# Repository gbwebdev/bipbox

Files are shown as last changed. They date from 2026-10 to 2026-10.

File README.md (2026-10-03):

# Bipbox

A self-hosted communication device for children — a wooden box with a thermal
printer, a telegraph key and a walkie-talkie, so that two kids in two different
homes can write, beep and talk to each other.

> **Status: in development.** The hardware exists (two boxes built); the
> software is being written. See [`docs/architecture.md`](docs/architecture.md).

## What it does

| Feature | |
|---|---|
| **Telex** | Family members log into a web page and send a text, a drawing or a photo. It prints on the box's thermal printer within seconds. |
| **Telegraphy** | Press the button on your box and the orange lamp lights up on the other one, with an optional beep. Nothing more — that is the charm. |
| **VoIP** | Squeeze the PTT on the shoulder speakermic and talk; your voice comes out of the other box's speaker. |

Boxes are grouped into **channels**. Everyone in a channel can beep and talk to
each other. People without a box can join from a browser.

## Hardware

Each box contains a Raspberry Pi Zero W, a MeanWell RS15-5 supply, a 4-port USB
hub, a USB sound card, an ESC/POS thermal printer and a homemade HAT that drives
four status lamps through a 74HCT595 and reads the buttons.

KiCad and FreeCAD sources are in [`CAD/`](CAD/) so you can build your own.

## Repository layout

```
server/   FastAPI server + Janus, deployed with docker-compose
device/   bipboxd daemon and the Pi's local management console
image/    pi-gen configuration producing a ready-to-flash SD image
docs/     architecture, specifications, hardware notes
CAD/      KiCad (HAT) and FreeCAD (enclosure)
```

## Documentation

| | |
|---|---|
| [`docs/architecture.md`](docs/architecture.md) | the design: topology, pin map, data model, protocol, security |
| [`docs/voip-options.md`](docs/voip-options.md) | why the voice path is Janus AudioBridge and not Mumble or WebRTC |
| [`docs/open-questions.md`](docs/open-questions.md) | the decisions behind the design, and why |
| [`docs/workflow.md`](docs/workflow.md) | branches, commits, releases |
| [`context.md`](context.md) | the original description of the project |

## Hardware bring-up

Before any of the software exists, the HAT can be tested on its own:

```bash
sudo apt install python3-spidev python3-gpiozero
sudo python3 device/tools/wiring_test.py
```

It discovers the shift-register bit order, measures button bounce, finds a
speaker-safe volume ceiling and prints a test ticket. See
[architecture.md §3.5](docs/architecture.md).

## Licensing

Two licences, scoped by what they cover:

| | |
|---|---|
| **Software** — everything outside `CAD/` | [MIT](LICENSE) |
| **Hardware** — the KiCad and FreeCAD sources in `CAD/` | [CERN-OHL-S v2](CAD/LICENSE) (strongly reciprocal) |

So you may do as you like with the code, and if you build on the board or the
enclosure and distribute the result, those improvements stay open.

## Acknowledgements

Bipbox grows out of [telex](https://github.com/gbwebdev/telex), an earlier
message-to-thermal-printer project; its printer handling, ESC/POS layout and
drawing tool are carried over here.

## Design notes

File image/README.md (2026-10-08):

# Golden image workflow

Capturing a prepared card and re-flashing it, so setting up a box is minutes
rather than an evening. This is the interim approach; `pi-gen` (phase 6) will
eventually build the image from source instead, which is reproducible and
diffable where a cloned card is neither.

## What belongs in the image, and what does not

| In the image | Per box, applied after flashing |
|---|---|
| Raspberry Pi OS Lite (Bookworm, **armhf** — the Pi Zero W is ARMv6) | hostname |
| `config.txt` | device UUID and server credentials |
| apt packages | **calibration** — the LED bit order is a property of each harness (§3.2) |
| WiFi credentials *(by default — see below)* | SSH host keys and `machine-id` (regenerated on first boot) |

Getting that split wrong is not a tidiness issue. Two boxes sharing a
`machine-id` derive the same DHCP client identifier and fight over a lease,
which presents as "the second box never appears on the network" — a long way
from its cause. And box A's calibration on box B lights the wrong lamps.

## 1. Prepare the card you want to clone

Install everything slow, so you never wait for it again. On a Pi Zero these
take a while:

```bash
sudo apt update && sudo apt full-upgrade -y
sudo apt install -y \
    python3-spidev python3-gpiozero python3-lgpio \
    python3-venv libusb-1.0-0 \
    gstreamer1.0-tools gstreamer1.0-plugins-base \
    gstreamer1.0-plugins-good gstreamer1.0-alsa alsa-utils \
    avahi-daemon git
```

Settle `config.txt` (§3.1) and confirm the box boots and joins WiFi **before**
capturing. An image made from a card you have not booted is a guess.

## 2. Strip box-specific identity

On the Pi, as root, immediately before shutting down:

```bash
sudo bash image/prepare-for-capture.sh              # keeps WiFi
sudo bash image/prepare-for-capture.sh --wipe-wifi  # for a shareable image
sudo shutdown -h now
```

### WiFi: kept by default, and why

Keeping the credentials is what makes a flashed card useful immediately — it
joins the bench network on its own and you can SSH straight in. **Never share
such an image**: NetworkManager stores the PSK in plain text.

Use `--wipe-wifi` for an image you intend to publish, or for a box destined
for another house, where your credentials would be wrong anyway. A card with
no known network falls back to AP mode and is configured from the local
console (§9.3) — which is the real deployment path for boxes that live
elsewhere.

Either way the script **always** deletes `custom.toml`, `userconf.txt`, `ssh`
and `wpa_supplicant.conf` from the boot partition. Those are consumed at first
boot, and they are far more exposed than anything under `/etc`: the boot
partition is FAT, so any computer can read them with no root and no ext4
driver — and `custom.toml` holds both the WiFi PSK and the user's password
hash in clear text. Leaving it would also re-apply its hostname on the next
first boot, fighting the per-box hostname set afterwards.

## 3. Capture

Move the card to a machine with a reader (not the Pi — a live root filesystem
cannot be imaged cleanly):

```bash
sudo bash image/capture.sh /dev/sdX bipbox-base
```

It reads only as far as the last partition, then uses
[PiShrink](https://github.com/Drewsif/PiShrink) to shrink the root filesystem
and install a first-boot hook that expands it again on whatever card it lands
on. A 32 GB card yields a few hundred megabytes rather than 32 GB — which is
the difference between a golden image you keep and one you abandon.

### If a flashed card joins WiFi but refuses SSH

That means **sshd has no host keys**. Connection *refused* rather than timing
out is the tell: the host is up and nothing is listening on 22.

Host keys must not be shared between boxes, so they are deleted during
preparation — but **sshd refuses to start with none**, and Raspberry Pi OS only
regenerates them as part of its first-boot flow, which a card that has already
booted never runs again. The script now installs and verifies a regeneration
unit *before* deleting anything, and aborts rather than producing an
unreachable image.

To rescue a card already in that state, generate the keys onto it offline:

```bash
sudo mount /dev/sdX2 /mnt
sudo ssh-keygen -q -t rsa     -b 3072 -f /mnt/etc/ssh/ssh_host_rsa_key     -N ''
sudo ssh-keygen -q -t ecdsa           -f /mnt/etc/ssh/ssh_host_ecdsa_key   -N ''
sudo ssh-keygen -q -t ed25519         -f /mnt/etc/ssh/ssh_host_ed25519_key -N ''
sudo umount /mnt
```

With console access, `sudo ssh-keygen -A && sudo systemctl restart ssh` is the
same fix, and `systemctl status ssh` shows
`sshd: no hostkeys available -- exiting`.

## 4. Write and verify

```bash
xz -dc bipbox-base-YYYYMMDD.img.xz | sudo dd of=/dev/sdX bs=4M conv=fsync status=progress
sync
```

**Always verify.** An unverified write cost an evening during bring-up, and the
failure is silent:

```bash
sudo blockdev --flushbufs /dev/sdX
echo 3 | sudo tee /proc/sys/vm/drop_caches >/dev/null
SIZE=$(xz -l --robot bipbox-base-YYYYMMDD.img.xz | awk '/totals/{print $5}')
sudo cmp -n "$SIZE" <(xz -dc bipbox-base-YYYYMMDD.img.xz) /dev/sdX && echo VERIFIED
```

New cards are worth checking once before you trust them at all:

```bash
sudo f3probe --destructive --time-ops /dev/sdX
```

## 5. Per-box setup after flashing

1. Set the hostname (`bipbox-<name>`).
2. Run the bit-walk — **each box needs its own**, because the two green lamps
   sit on identical 300 Ω positions and the assignment comes from how the
   harness was crimped, not from the PCB:
   ```bash
   sudo python3 device/tools/wiring_test.py --leds
   ```
3. Install the resulting `wiring_test.json` as `/etc/bipbox/calibration.json`.
4. Enter the server URL and device credentials.

## Keep a spare

Keep one card flashed and ready. It turns a dead card from an evening of
diagnosis into a sixty-second swap, and cards do die — two did during bring-up.

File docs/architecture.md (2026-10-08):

# Bipbox — Architecture

Version 0.1 — 2026-10-03 — **for review before implementation**

Derived from [`../context.md`](../context.md), the 46 answers in
[`open-questions.md`](./open-questions.md) and the transport survey in
[`voip-options.md`](./voip-options.md). Where this document and `context.md`
disagree, this document wins and `context.md` should be corrected.

Open decisions still needing your input are marked **[OPEN]**. There are three.

---

## 1. System overview

```
   ┌─ Browser (parent/grandparent) ──────────────────────────────────────┐
   │  HTTPS + WSS  ──────────────► Cloudflare proxy ──► bipbox server    │
   │  WebRTC media (UDP) ─────────────────────────────► Janus  [OPEN-1]  │
   └─────────────────────────────────────────────────────────────────────┘

   ┌─ Bipbox (Pi Zero W) ────────────────────────────────────────────────┐
   │  HTTPS + WSS  ──────────────► Cloudflare proxy ──► bipbox server    │
   │  plain RTP (G.711) ──► WireGuard tunnel ────────► Janus AudioBridge │
   └─────────────────────────────────────────────────────────────────────┘

                    ┌──────────── your host ─────────────┐
                    │  bipbox-server  (FastAPI)          │
                    │  janus          (AudioBridge MCU)  │
                    │  wireguard      (hub)              │
                    │  SQLite + image store (volumes)    │
                    └────────────────────────────────────┘
```

Two planes, deliberately separated:

- **Control plane** — everything except voice. HTTPS/WSS through the Cloudflare
  proxy. Telex messages, telegraphy events, presence, config, admin, LED state.
  No inbound ports on your IP; Cloudflare is the only front door.
- **Media plane** — voice only. UDP. Never through Cloudflare (which cannot
  carry it). Devices reach it inside WireGuard; browsers reach it directly
  (**[OPEN-1]**).

Because the media plane is plain RTP — no DTLS, no SRTP, no ICE on the Pi — its
confidentiality and authentication come **entirely** from the tunnel. That is
the trade that lets an ARMv6 chip do zero codec and zero crypto work.

---

## 2. Components

| Component | Tech | Where |
|---|---|---|
| `bipbox-server` | Python 3.11, FastAPI, SQLModel, SQLite | Docker, behind Cloudflare |
| `janus` | Janus Gateway + `audiobridge` plugin | Docker, same host |
| `wireguard` | kernel WireGuard | the host, or your OpenWRT VM (**[OPEN-2]**) |
| `bipboxd` | Python 3.11, asyncio | Pi Zero W, systemd |
| local console | Python 3.11, Flask | Pi Zero W, systemd, port 80 |
| audio pipeline | GStreamer 1.0 (Debian armhf packages) | Pi Zero W, inside `bipboxd` |

### 2.1 Why two processes on the device, not five

`bipboxd` owns every shared resource: the SPI bus and the '595, the GPIO lines,
the ALSA device, the printer, and the single WebSocket to the server. Telex,
telegraphy and VoIP are asyncio tasks inside it, not separate services. The
local console is a separate Flask process (sync, trivially simple, must survive
`bipboxd` crashing) and talks to the daemon over a Unix socket at
`/run/bipbox/ctl.sock`.

Note for the record, since it came up: **SPI and USB share nothing.** SPI0 is a
dedicated peripheral; USB is the OTG port feeding the hub. The sound card and
printer do share that one USB port, which is 480 Mbit/s against a 64 kbit/s
audio stream — irrelevant.

---

## 3. Hardware interface

### 3.1 Pin map (authoritative)

| Function | Pin | Direction | Notes |
|---|---|---|---|
| Power button | GPIO3 | in | `dtoverlay=gpio-shutdown`; wake-from-halt is firmware. No software. |
| Telegraphy button | GPIO2 | in | Active low. External 1.8 kΩ pull-up + RC debounce on the HAT. |
| PTT | GPIO23 | in | Active low. **Internal** pull-up enabled in software. |
| Pi activity LED | GPIO26 | — | `dtparam=act_led_gpio=26`. Kernel-driven, no software. |
| '595 SER | GPIO10 / SPI0 MOSI | out | |
| '595 SRCLK | GPIO11 / SPI0 SCLK | out | |
| '595 RCLK | GPIO7 / SPI0 CE1 | out | `/dev/spidev0.1` |

`config.txt` additions: `dtparam=spi=on`, `dtparam=act_led_gpio=26`,
`dtoverlay=gpio-shutdown,gpio_pin=3`.

### 3.1a Assembly hazard: the 40-pin header has no keying

**A Pi Zero W was destroyed this way on 2026-10-08.** The HAT was fitted with
its even-numbered row sitting on the Pi's odd-numbered row — one row across,
with the HAT's first row hanging off the end entirely. Nothing about the
connector prevents it.

| HAT pin | lands on Pi pin | consequence |
|---|---|---|
| 2 — **+5 V** | 1 — **3V3** | **5 V forced onto the Pi's 3.3 V rail** |
| 4 — **+5 V** | 3 — GPIO2 | 5 V onto a 3.3 V-max GPIO |
| 6 — GND | 5 — GPIO3 | GPIO3 shorted to ground |

5 V on the 3V3 rail is the classic fatal Pi mistake: that rail feeds the SoC
I/O, the SD interface and the BCM43438 WiFi module. The symptom was a board
that blinked its ACT LED, never joined WiFi (the radio was already gone), and
grew too hot to touch over two or three minutes. It did not survive.

**Design fix for the next PCB revision: a shrouded 2×20 header**, which makes
the misalignment physically impossible. It is a trivial BOM change and this
board is meant to be opened for servicing, so the mistake will recur otherwise.

**Until then, the assembly procedure is:**

1. Test-fit on the dead Pi first — it is now the alignment dummy.
2. Confirm pin 1 of the HAT sits on pin 1 of the Pi, by eye, every time.
3. With the HAT powered and **no Pi fitted**, confirm header pins 1 and 17
   (3V3) read ≈ 0 V. The HAT only consumes 3.3 V; it never sources it, so any
   voltage there means a bridge that will kill the next Pi too.
4. Keep a finger on the SoC for the first thirty seconds after power-up.

Also worth knowing after any such event: GPIO2 is the telegraphy button. A Pi
can survive the 3V3 insult and still have that single pin damaged, so test it
explicitly with `wiring_test.py --buttons` rather than assuming.

### 3.1b Keep the fleet uniform: Pi Zero W, not Zero 2 W

Both boxes use the **Pi Zero W (ARMv6)**, and replacements should match.

The Zero 2 W is pin-compatible, runs the same armhf image, and is roughly four
times the CPU — tempting after an ARMv6-driven design. Two reasons not to:

- **Both boxes run the same software, so the weakest box sets the constraints.**
  While box A is a Zero W, a faster box B buys nothing and the G.711/plain-RTP
  design (`voip-options.md`) stands either way.
- **UUGear document a real risk with the Zero4U hub**: the Zero 2 W's stronger
  WiFi radiation can interfere with USB devices on some ports and make them
  unstable. This box runs the *sound card* and the *printer* over that hub, and
  unstable isochronous USB is indistinguishable from bad audio — it would
  poison the phase 0b measurements.

A Zero 2 W is an acceptable fallback if Zero W stock runs out, but it is a
knowing trade, and audio dropouts become the first thing to suspect.

### 3.2 Driving the 74HC(T)595 over hardware SPI

Using CE1 as the latch is neat and it works: spidev holds CS low for the
transfer and releases it high afterwards, and that **rising edge is exactly what
RCLK needs**. SPI mode 0 (CPOL=0/CPHA=0) shifts data out on the falling clock
edge while the '595 samples on the rising edge — compatible. One byte per
update, written only when the byte changes.

Output mapping, shifting MSB-first (so the first bit sent lands on QH). Taken
from the KiCad netlist, which is authoritative for the resistors but — see
below — **not** for which LED is which:

| Bit | '595 output | Series R | Goes to | LED |
|---|---|---|---|---|
| 5 | QF | R2, 180 Ω | J5.5 | blue **or** orange |
| 4 | QE | R3, 300 Ω | J5.4 | one of the two greens |
| 3 | QD | R4, 300 Ω | J5.3 | the other green |
| 2 | QC | R5, 180 Ω | J5.2 | orange **or** blue |
| 0,1,6,7 | QA,QB,QG,QH | — | unconnected | unused, held 0 |

(J5.1 is ground, and J5.6 is the always-on power LED: +5V through R1, 180 Ω,
with no software involvement.)

**The board cannot tell you which green is telex and which is VoIP.** QD and
QE are electrically identical — same 300 Ω, adjacent pins on the same
connector — so the assignment is a property of **how the LED harness was
crimped**, not of the PCB. The same is true of QC and QF: both 180 Ω, so
orange-vs-blue is also a harness question, though those two are at least
distinguishable by eye.

It follows that the mapping **must be discovered per box and stored**, not
assumed. The bit-walk in §3.5 exists precisely for this, and two boxes may
legitimately differ.

**Measured on box A (2026-10-07), confirming the prediction:**

| Bit | Output | LED | vs. `context.md` |
|---|---|---|---|
| 2 | QC | telegraphy (orange) | as assumed |
| 3 | QD | **VoIP** (green) | **swapped** |
| 4 | QE | **telex** (green) | **swapped** |
| 5 | QF | WiFi (blue) | as assumed |

The two 180 Ω positions (QC/QF) came out as guessed; the two identical 300 Ω
positions (QD/QE) came out reversed — exactly where the board carries no
information. `context.md` should be corrected to drop the claim.

On the chip: you're swapping to **74HCT595N** (F2). Software is unaffected —
the fix is purely about input thresholds, so develop against the 74HC595N now
and nothing changes when you re-solder.

### 3.3 PTT wiring variants

Two boxes, two speakermics, two PCB build variants:

| Box | Speakermic | HAT variant | PTT electrical path |
|---|---|---|---|
| A | Baofeng BF-T1/T8/U9/UV-3R+ | Wiring 1 | Dedicated ring → switch to GND |
| B | Yaesu/Vertex VX-3R, FT-60R… | Wiring 2 | Mic bias → 10 kΩ → 2N7000 gate → drain |

**They are NOT the same polarity — corrected 2026-10-08 after variant 2 failed
on the bench.** The config carries `ptt_wiring: dedicated | shared`, and the
polarity follows from it (`Calibration.ptt_active_low`):

| Variant | Idle | Pressed |
|---|---|---|
| `dedicated` | pin pulled high by the pull-up | switch grounds it → **LOW** |
| `shared` | mic-line bias keeps the transistor conducting → pin **LOW** | bias collapses, transistor opens → pin **HIGH** |

So variant 2 is **active-high**, the opposite of variant 1 and of the
telegraphy key. Wiring 2 also has an RC on the gate (10 kΩ + 100 nF ≈ 1 ms), so
its edges are slower and it gets a wider debounce window by default (50 ms,
against 20 ms for the dedicated variant).

#### Variant 2 (shared mic/PTT) does not work as designed

Found 2026-10-08: on the shared-wiring board, **neither PTT nor the microphone
worked**, and both failures have one cause.

```
TRRS ring 2 ──┬── C11 1µF ── sound card mic tip
              └── R10 10k ──┬── Q2 2N7000 gate ── drain → GPIO23
                            └── C3 100nF ── GND
```

**C11 blocks DC, and DC is what both functions depend on.** The electret
element needs a bias voltage to produce any signal, and the sound card supplies
one — but the series capacitor stops it reaching the element. The 2N7000's gate
is fed from the same line, so with no DC there it never reaches V_GS(th) either.
No bias, therefore no audio *and* no PTT.

Three further problems in that circuit, in order of importance:

1. **Bypass C11** so the card's own bias feeds the line. Audio then flows and
   the line's DC level (biased when idle, collapsed when pressed) drives the
   gate. One component removed rather than a bias network added.
2. **The 2N7000 is the wrong part.** Its V_GS(th) is 0.8–3.0 V and a biased mic
   line sits around 1–2 V: inside the band where it works on one sample and not
   another. An **NPN (BC547/2N3904)** switches at ~0.6 V and reuses R10 as its
   base resistor.
3. **The gate has no pull-down.** With no speakermic plugged in the line is
   open and the gate floats, leaving GPIO23 undefined. A **100 kΩ gate-to-
   ground** gives a defined "not pressed" when unplugged.

One thing to measure before trusting the topology at all: whether PTT takes the
line to *exactly* 0 V or to an intermediate voltage. A dead short also shorts
the microphone, making audio and PTT mutually exclusive on a shared line; a
series resistor in the switch lets both coexist. Yaesu speakermics usually do
the latter, but it is a property of the speakermic, not of the board.

### 3.4 LED state machine

One `LedController` task ticking at **40 Hz (25 ms)**. Each LED resolves to a
pattern from (service state) with (activity) overriding it while active, per
Q31.

The tick is 25 ms rather than 20 because **every timing below is a multiple of
25 ms**, so each phase runs at exactly its written duration. At a 20 ms tick,
175 ms and 550 ms would quantise to 180 and 560, and a pattern would not be
what the table says. A test enforces the alignment.

Timings (Q30, with the AP pause removed as you asked):

| Pattern | Definition |
|---|---|
| `off` / `on` | steady |
| `slow` | 550 ms on / 550 ms off |
| `fast` | 175 ms on / 175 ms off |
| `heartbeat` | 200 ms on / 2800 ms off — a **3 s** cycle |
| `ap` | 200 on, 200 off, 200 on, 200 off, 500 on, 200 off — repeating, no pause |
| `flash` | activity: `fast`, held **350 ms**, and it **starts dark** |

**The flash needed two corrections, both found by implementing it.** Activity
is shown on a lamp that is usually *steady-on* (telex connected, then
receiving), so:

- It must last **at least one full `fast` cycle** (350 ms). A shorter flash can
  land entirely inside the pattern's lit phase and produce no visible change
  whatsoever — invisible exactly when it matters.
- It must **open with the dark phase**. On a lit lamp only a gap registers, so
  the flash carries its own phase origin rather than following the global one.
  Repeated flashes extend it without restarting that phase, so sustained
  activity reads as continuous blinking instead of a stutter.

**Tuned on the real LEDs over two passes**, which is why the pattern preview
exists — every one of these read too brief or too quick on paper:

- `fast` went 100 → 125 → **175 ms** per phase. It is now 2.9 Hz against
  `slow`'s 0.9 Hz, a 3.1× ratio. **That ratio is the constraint**: both appear
  on the *same* lamp at different times (telex `slow` = connecting,
  `fast` = receiving), so they must stay tellable apart. Lengthening `fast`
  again means lengthening `slow` too; a test guards the margin.
- `heartbeat` went 80/1920 → 130/1970 → **200/2800**, a deliberate 3 s cycle.
  Proportional scaling suggested 186/2814; rounded to 200/2800 for round
  numbers, an exact 3.000 s period, and a visibly longer flash. The 14× gap
  ratio keeps it reading as a heartbeat rather than a slow blink.

| LED | off | slow | fast | on | heartbeat |
|---|---|---|---|---|---|
| **WiFi** (blue) | down | searching | connecting | connected | — |
| | | | | *`ap` pattern when in AP mode* | |
| **Telex** (green) | client down | connecting | *activity:* receiving/printing | connected | — |
| **VoIP** (green) | client down | connecting *or tunnel down* | *activity:* tx/rx audio | connected | — |
| **Telegraphy** (orange) | connected, idle | connecting | — | **someone else is pressing** | client down |

Note the telegraphy LED is inverted relative to the others: its *steady on* is
the event, and "all well" is off. That is per spec and intentional.

### 3.4a Known hardware fault: the telegraphy button cannot be read

**Found during bring-up on 2026-10-07: GPIO2 never goes low when the
telegraphy button is pressed, so the button does nothing.** This is a board
design fault, not a software one, and it needs a rework.

From the netlist, the button path is:

```
GPIO2 ──[R9 10k]── node ──[R7 1k]── J1.2 ── switch ── GND
                     └──[C6 2.2µF]── GND
```

GPIO2 is one of the two pins carrying a **fixed 1.8 kΩ pull-up to 3V3 on the
Pi itself** (it is I2C SDA; the pull-up is on the Pi board and cannot be
disabled). With the button pressed, the pin therefore sits at a divider:

```
3.3 V × 11 kΩ / (1.8 kΩ + 11 kΩ) ≈ 2.84 V
```

against a logic-low threshold near 0.9 V. The pin reads **high whether the
button is pressed or not**. No amount of software fixes this.

**Recommended rework: bridge out R9 and R7** (replace both with wire links or
0 Ω). GPIO2 then connects straight to the switch, with C6 still across it:

- pressed → 0 V, unambiguously low
- released → recharges through the 1.8 kΩ pull-up, ≈ 4 ms, so the button is
  also *faster* than designed
- C6 still provides the debounce the RC was there for

Rejected alternatives:

- *Bridge only R9*: leaves 1 kΩ against 1.8 kΩ → 1.18 V pressed, still above
  threshold. Fails.
- *Move the button to a free GPIO* (GPIO17/22/27 are unconnected on the HAT):
  works, since the internal ~50 kΩ pull-up gives ≈ 0.6 V pressed — but the
  release then takes ≈ 110 ms to recharge 2.2 µF through 50 kΩ, which is
  sluggish for a button whose whole job is immediacy. More invasive and worse.

For the next PCB revision: keep the RC, but put the button on an ordinary GPIO
and the pull-up resistor on the HAT, rather than relying on a pin whose
pull-up is fixed at 1.8 kΩ.

GPIO23 (PTT) is unaffected — the netlist confirms it goes to `JP3` and the
2N7000 drain with no series resistance, and it uses the internal pull-up.

### 3.5 `wiring_test.py` — standalone hardware bring-up tool

`device/tools/wiring_test.py`: one file, no project dependencies, runnable as
`sudo python3 wiring_test.py` on a bare Raspberry Pi OS Lite install. It exists
so the HAT can be brought up and iterated on **before any of bipbox exists**,
and it stays afterwards as a field diagnostic.

It deliberately avoids `python-escpos`, `pyusb` and anything from `bipboxd`:
printing is raw ESC/POS bytes written to `/dev/usb/lp0` or `/dev/ttyACM*`, audio
is `aplay`/`arecord`, so the only requirement is
`apt install python3-spidev python3-gpiozero`.

What it does:

- **LED bit-walk** — lights each '595 output in turn, asks which LED lit, and
  writes the discovered bit map to `wiring_test.json`. This converts §3.2's bit
  order from an assumption into a measured fact.
- **LED by name**, and a **preview of every blink pattern** from §3.4, so the
  timings can be judged on real LEDs rather than on paper.
- **Button monitor** — live state of GPIO2 and GPIO23 with transition counts and
  **measured bounce duration**. This is what settles whether the two PTT wiring
  variants (§3.3) need different debounce values, instead of guessing.
- **Audio** — tone to the speaker, then record-and-play-back from the mic, with
  a level meter. Exercises the TRRS wiring and the UGREEN card. **Starts at 40%
  and never jumps to full scale**, to protect the speaker.
- **Volume sweep** — steps the hardware mixer upward from 10%, stopping the
  moment it is told the tone is too loud, distorted or buzzing, and writes the
  last good level to `wiring_test.json` as the proposed `volume_max_pct`
  (§6.3.1). Prompts for confirmation before every step above 70%.
- **Printer** — detect and print a test ticket.
- **`--selftest`** — runs everything in sequence with a PASS/FAIL summary.

### 3.6 Box A calibration — the bring-up result

Bring-up finished 2026-10-07. The tool's `wiring_test.json` is not a scratch
file: **it is the calibration for that box**, and the daemon reads the same
values from `/etc/bipbox/calibration.json` (seeded from it by the installer).
Nothing here is derivable from the schematic, so it cannot be recreated by
inspection — only by walking the hardware again.

```json
{
  "led_bits":        { "telegraphy": 2, "voip": 3, "telex": 4, "wifi": 5 },
  "mixer_control":   "Speaker",
  "volume_max_pct":  90,
  "playback_gain":   4,
  "capture_control": "Mic",
  "capture_pct":     60
}
```

| Value | Note |
|---|---|
| `led_bits` | QD/QE reversed from the guess (§3.2). Per-box. |
| `mixer_control` / `capture_control` | This UGREEN card exposes **`Speaker`** and **`Mic`**, not `PCM`. The daemon must use the *saved* names rather than re-probing, so a card swap is a deliberate recalibration. |
| `volume_max_pct` 90 | Chosen knowingly above the 75% caution point: walkie-talkie distortion is acceptable here, and the speaker is in no danger (§6.3.2). |
| `playback_gain` ×4 | Validates §6.3.3 — spending crest factor is what made speech audible. |
| `capture_pct` 60 | **Lower than the 80 I had assumed.** The mic was never weak; it was simply that no capture control was being set at all. Above 60 it clipped. |

**Longevity note, not a warning:** 90% mixer plus ×4 clipped gain means the
codec is driven near full scale into a ~12 Ω load whenever VoIP is active —
the hardest configuration for it. That is an informed trade for loudness, and
the sound card is a cheap, socketed, replaceable part. If one ever fails, this
is the first thing to look at rather than a mystery.

---

## 4. Data model

SQLModel, SQLite. Ported from telex where it already fits.

```python
Channel(id, slug UNIQUE, name, janus_room, created_at)

Device(uuid PK, channel_id FK, alias, secret_hash,
       paper_cols=42, paper_dots=576, printer_info, ptt_wiring,
       wg_pubkey, wg_ip, fw_version,
       last_seen, ip_address, mac_address, enabled, created_at)
# Hardware calibration (§3.6) deliberately does NOT live here: LED bit order,
# mixer control names and gain settings are properties of one physical box and
# its harness, useless to the server, and needed before the box can even reach
# it. They stay in /etc/bipbox/calibration.json on the device.

Account(id, login UNIQUE, display_name, password_hash,
        totp_secret, is_admin, enabled, created_at, last_login)

Membership(id, account_id FK, channel_id FK,
           can_telex, can_voip, can_telegraphy, all_devices)
MembershipDevice(membership_id FK, device_uuid FK)      # when all_devices=False

Message(id, channel_id FK, author_account_id, author_device_uuid,
        text, image_path, image_mode, created_at)
Delivery(id, message_id FK, device_uuid FK, status,
         created_at, delivered_at, printed_at, error_msg)

FailedAttempt(id, ip, subject, scope, attempted_at)     # scope: human | device
IPBan(id, ip, subject, scope, level, banned_at, banned_until, active, lifted_at)

Setting(key PK, value)                                  # admin-tunable runtime config
VoipEvent(id, channel_id, participant, started_at, ended_at)   # only if enabled

WgPeer(id, kind, device_uuid, account_id, label,        # kind: device | browser
       pubkey UNIQUE, wg_ip UNIQUE, created_at, last_handshake, enabled)

Webhook(id, event, url_template, method, headers_json, auth_kind, auth_secret,
        allow_insecure_tls, body_template, timeout_s, retries, enabled)
```

Decisions baked in:

- **One channel per device** (Q11): `Device.channel_id`, not a join table.
- **Many channels per account** (Q12): `Membership` is a join table, because it
  costs nothing now and retrofitting it later costs a migration. The admin UI
  exposes a single channel per account until you ask for more.
- **Images on disk** (Q20): `Message.image_path`, not base64 in SQLite.
  `image_mode` records `dither` or `threshold` so a reprint reproduces exactly
  what was printed.
- **`Setting`** holds retention days, VoIP-metadata logging (off by default,
  Q8), alert thresholds, bip defaults.
- **`FailedAttempt.scope`** separates human from device bans (F4.3) so a box
  with a stale secret can never permanently ban your home IP, and with it the
  sibling box.

### 4.1 Password hashing — deliberately two algorithms

| Secret | Algorithm | Why |
|---|---|---|
| `Account.password_hash` | **Argon2id** | Human-chosen, low entropy, needs to be slow. |
| `Device.secret_hash` | **HMAC-SHA256** with a server-side pepper | 32 bytes from `secrets.token_urlsafe` — ~190 bits. Brute force is not a threat model, and this is verified on *every* reconnect, so paying bcrypt there is waste, not safety. |

### 4.2 Database engine: SQLite only, but kept portable

**There is no added value in offering a SQLite/Postgres choice here, and a real
cost in offering it** — a second backend doubles the migration and test surface,
and asks every third-party builder to make a decision they have no basis for.

The scale argues plainly: a handful of devices and accounts, a few messages a
day. SQLite's only structural limit is its single writer, and with WAL mode
readers never block it. Our writes are message inserts, delivery transitions and
heartbeats — telegraphy isn't even persisted (Q32). Postgres wins on multiple
app instances, heavy concurrent writes and a network-separated database; none of
those are in this project's future. Meanwhile SQLite is one file, which makes
backups *easier* (`sqlite3 .backup`, or Litestream for continuous copies).

So: **ship SQLite, and spend the small effort that keeps Postgres a
`DATABASE_URL` change rather than a rewrite.** Three concrete rules:

1. **Alembic for migrations**, not telex's idempotent
   `ALTER TABLE … ADD COLUMN` wrapped in `try/except` (`database.py:_migrate`).
   That pattern cannot rename a column, change a type or migrate data, and it
   silently swallows genuine errors. Alembic is portable and reversible, and
   this project will have real schema evolution.
2. **No backend-specific SQL.** Everything through SQLModel/SQLAlchemy
   constructs; no SQLite-only functions or pragmas in query code.
3. **Async driver: `aiosqlite` with async SQLAlchemy sessions.** This one is not
   about portability, it is correctness: the server holds long-lived WebSockets,
   and a synchronous DB call on the event loop stalls *every* connected box, not
   just one request. (Telex got away with sync sessions because it was pure
   request/response.) The same choice maps to `asyncpg` if Postgres ever
   happens.

SQLite is opened with WAL, `foreign_keys=ON` and a `busy_timeout`.

---

## 5. Control-plane protocol

### 5.1 Device ↔ server WebSocket

One connection, `wss://<server>/api/device/ws`. Credentials on the HTTP upgrade
(`X-Device-ID`, `X-Device-Secret`). JSON frames, `{"t": "<type>", ...}`.
Heartbeat: server `ping` every 20 s, device must answer within 10 s; the device
reconnects with exponential backoff capped at 30 s.

**Server → device**

| `t` | Payload | Effect |
|---|---|---|
| `hello` | `server_time`, `channel`, `alias`, `paper_cols`, `settings` | Clock source (F3) and config refresh |
| `telex` | `delivery_id`, `sent_at`, `sender`, `text`, `image_url`, `image_mode` | Spool and print |
| `telegraphy` | `active: bool`, `from: alias` | Orange LED on/off + local bip |
| `voip` | `action: join|leave`, `room`, `rtp: {...}` | Join/leave the AudioBridge room |
| `command` | `reprint_ticket | test_print | check_update | reboot` | From the admin console |
| `ping` | — | |

**Device → server**

| `t` | Payload |
|---|---|
| `hello` | `fw_version`, `printer_info`, `paper_cols`, `ip`, `mac`, `uptime` |
| `ack` | `delivery_id`, `status: printed|failed`, `error` |
| `telegraphy` | `pressed: bool` |
| `ptt` | `active: bool` (presence/UI only — media goes to Janus, not here) |
| `status` | `printer_ok`, `queue_depth`, `wifi_rssi`, `cpu_temp` |
| `pong` | — |

**Catch-up on connect** (Q3, Q19): after `hello` the server pushes every
`pending` delivery for that device, which is what makes "print what arrived
while we were off" work without a polling loop.

### 5.2 Telegraphy fan-out

A press is broadcast to every *other* member of the channel (devices and web
clients) and is **not persisted** (Q32). The server tracks a per-channel set of
currently-pressing participants and sends `telegraphy{active}` on set
empty↔non-empty transitions only, so a device holding the button doesn't
generate traffic and a second presser doesn't retrigger the first's LED.

### 5.3 HTTP API

| Auth | Prefix | Used by |
|---|---|---|
| session cookie + TOTP | `/api/admin/*` | admin console |
| session cookie | `/api/client/*` | web clients |
| `X-Device-ID` + `X-Device-Secret` | `/api/device/*` | boxes (provisioning, image fetch, ACKs) |

Routes are explicit — telex's catch-all `@app.get("/{filename}")` (F4.2) is
dropped. Page routes: `/admin`, `/{channel}`, `/{channel}/{device}`, with a
reserved-slug list so no channel can be called `admin`, `api` or `static`.

---

## 6. Media plane

### 6.1 Janus AudioBridge

One **AudioBridge room per channel** (Q5c), created on demand from the channel
definition so adding a channel needs no Janus configuration by hand. Room
config: `sampling_rate = 8000`, `allow_rtp_participants = true`, recording
disabled.

- **Devices** join as **plain RTP participants** with `codec: pcmu` — the `rtp`
  object in the join request carries the device's tunnel IP and port. No
  WebRTC, DTLS, ICE or SRTP on the Pi; µ-law is a lookup table, so codec cost is
  effectively zero.
- **Browsers** join the same room as ordinary WebRTC participants (Opus), and
  Janus transcodes into the mix.
- The server drives Janus over its HTTP API on localhost. Janus's own admin
  surface is never exposed.
- **Two independent RTP port ranges**, verified against Janus 1.4.2 during the
  phase 0b spike and worth stating because it is a silent failure mode:
  plain-RTP participants are bound from `rtp_port_range` in
  **`janus.plugin.audiobridge.jcfg`** (default 10000+), while
  `media.rtp_port_range` in `janus.jcfg` governs only ICE/WebRTC media. Both
  must be set, and both opened — on the tunnel for the devices, and on the
  public interface for browsers in `plain_rtp` mode. Getting this wrong
  produces audio that is silent with no error in any log.
- The `ip` Janus reports in a join response is **its own view of itself** (a
  container or tunnel address), not necessarily one the device can reach. The
  device always sends to the address it was given in its configuration.
- Mixing is server-side, so each box receives exactly **one** stream regardless
  of how many participants exist, and **nobody is ever sent their own audio** —
  "except loopback" is free.
- Two simultaneous PTTs are simply mixed (Q7).

### 6.2 Device audio pipeline (GStreamer)

```
TX (while PTT held):
  alsasrc ! audioconvert ! audioresample ! audio/x-raw,rate=8000,channels=1
          ! mulawenc ! rtppcmupay ! udpsink host=<janus-wg-ip> port=<p>

RX (always):
  udpsrc port=<q> ! application/x-rtp,encoding-name=PCMU
          ! rtpjitterbuffer latency=60 ! rtppcmudepay ! mulawdec
          ! audioconvert ! audioresample ! alsasink
```

All elements come from Debian armhf packages. **We write no jitter buffer** —
`rtpjitterbuffer` is mature and tunable, and it was the main thing I had
wrongly credited Mumble with providing.

Latency budget against the < 150 ms target (< 500 ms worst case, Q10): 20 ms
frame + 60 ms jitter buffer + network RTT + ~20 ms ALSA. The jitter buffer is
the tuning knob the spike exists to set.

### 6.3 Half-duplex and the bip

- PTT held → TX starts, **local speaker muted** (Q6). Released → TX stops,
  speaker unmuted.
- The **bip** is generated locally on the Pi (Q9) — telegraphy sends only
  press/release events, never audio. Default 880 Hz with a short
  attack/release to avoid clicks; frequency, volume and on/off live in the local
  console.
- Bip and VoIP playback are mixed through ALSA **`dmix`**, since the UGREEN card
  won't mix in hardware.

### 6.3.1 Output level and speaker protection

The speakermic holds a small, cheap driver behind a 22 Ω series resistor, and
what kills a driver like that is **sustained** level, not peaks. So the design
puts a hard ceiling below every user-facing control:

| Setting | Where it acts | Range |
|---|---|---|
| `volume_max_pct` | **ALSA playback mixer** | 0–100%, **measured: 70** |
| `voip_volume_pct` | software gain, VoIP branch | 0–100% **of the ceiling** |
| `bip_volume_pct` | software gain, bip generator | 0–100% **of the ceiling** |
| `capture_pct` | **ALSA capture mixer** | 0–100%, set by the §3.5 mic sweep |
| `voice_gain` | software gain + hard limiter, playback | ×1–×8, user-facing (§6.3.3) |

**Measured 2026-10-07 on the first box: 70% is the ceiling.** 80% is still
tolerable but a faint buzz is audible, so 70 is the last clean step and becomes
the default `volume_max_pct` — replacing the provisional 40.

Capture needs the opposite treatment: the speakermic is a low-output element
into a cheap USB codec, and at the card's default the recording is nearly
inaudible. So capture gain is a **setting in its own right**, found by the mic
sweep (§3.5) and stored per device — there is no useful universal default, and
the two speakermic variants will not agree.

Why the ceiling lives in the hardware mixer rather than in software gain: the
mixer is the last stage before the amplifier, so it bounds the analogue output
**regardless of what any software does** — a bug in the bip generator or a
malformed RTP payload cannot exceed it. Software gain alone would leave the amp
running at full scale and merely hope the samples stay small.

Conversely the two user controls are software gains, because the bip and VoIP
need *independent* levels and there is only one mixer.

Rules:

- `bipboxd` owns the mixer: it asserts `volume_max_pct` at startup and after any
  change, so nothing else drifts it. ALSA state is also saved across reboots.
- The mapped (perceptual) ALSA scale is used — `amixer -M` — so a percentage
  behaves like a percentage on a slider rather than like a register value.
- **Both the output volume and the mic gain are user-facing** in the local
  console, side by side, because in practice neither has a setting that works
  untouched: the output is quiet (see §6.3.2) and the two speakermic variants
  need different capture gains. The mic gain control carries a **live level
  meter** — a gain slider without one is guesswork, and the same healthy
  window the bring-up sweep uses (25–85% peak) is drawn on it.
- Raising `volume_max_pct` shows a **warning** in the local console, and it sits
  in an advanced section rather than beside the everyday volume control.
- Boxes ship at `volume_max_pct = 70` (the measured ceiling) with the user
  volume well below it, so a freshly flashed card can never arrive loud.
- If the sweep concludes that even ~20% is too loud, that is a **hardware**
  answer, not a software one: solder the 47 Ω in parallel with the 22 Ω and
  attenuate there, rather than running the amplifier at the very bottom of its
  range where SNR is worst.

The same ceiling applies to the test tone and the printer-less startup beep —
there is no code path to the speaker that bypasses it.

### 6.3.2 Why playback is quiet, and why it is a hardware fix

**Found 2026-10-07: playback is too quiet even at the 70% ceiling, and the
cause is resistive, not software.** From the netlist, the output chain is:

```
sound card speaker out (J3.3) ──[R11 22Ω]── J4.4 (TRRS tip) ── speaker
                                     └──[R12 47Ω]── GND
```

R11 in series with a low-impedance speaker is a voltage divider, and it throws
away most of the signal:

**The schematic's 22 Ω for R11 is stale: the boards are built with 3.3 Ω**, and
have been throughout testing. The measured speaker is **8.6 Ω**. So the real
numbers are:

| Stage | Value |
|---|---|
| Attenuation, R11 = 3.3 Ω into 8.6 Ω (R12 fitted) | **−3.3 dB** |
| Same with R12 removed | −2.8 dB (so removing it gains 0.5 dB — pointless) |
| Maximum possible gain left, shorting R11 | +3.3 dB |

**There is therefore no meaningful hardware gain left on this path, and no
software gain either** — the mixer cannot exceed 0 dBFS without clipping. The
output is quiet because **the USB codec cannot drive this load any louder**: a
headphone-class output into ~12 Ω runs at or past its current limit. If louder
is genuinely required, the honest answer is a small amplifier module
(PAM8302-class) between the card and the speaker, not another resistor.

Action: **`CAD/` should be updated so the schematic says 3.3 Ω**, since it is
published for others to build from.

#### What is actually at risk

| Part | Risk | Why |
|---|---|---|
| **Speaker** (8.6 Ω) | **None** | It receives tens of milliwatts against a rating of several hundred — roughly 2–3% of capacity. It cannot be damaged by anything this card can produce. |
| **USB sound card** | **The real one** | It is driving ~12 Ω where 16–32 Ω is specified. Codecs of this class current-limit rather than fail, but sustained overdrive means sustained heat in the output stage. |

So `volume_max_pct` protects the **card**, not the speaker — and the right
setting is simply *below where distortion starts*, because audible distortion
is the symptom of the card being pushed past its limit. The 70% you measured is
already that number, arrived at for the wrong stated reason. **This corrects the
rationale in §6.3.1**; the ceiling model itself stands.

Practically: you can set the user volume anywhere up to the ceiling without
worrying about the speaker, and the ceiling is a card-longevity setting rather
than a safety interlock.

### 6.3.3 Making speech carry: crest factor, not volume

**Observed 2026-10-07: the test tone is comfortably loud while recorded speech
has to be strained for — at the same mixer setting.** That is not a fault, and
no volume control fixes it. It is crest factor:

| Signal | Peak | RMS | Crest |
|---|---|---|---|
| Sine (the test tone) | 0 dBFS | −3 dB | **~3 dB** |
| Speech | 0 dBFS | −14 to −20 dB | **14–20 dB** |

Loudness follows RMS, not peak. Normalised to the same peak, speech carries
**10–17 dB less average power** than a tone. The chain is behaving correctly;
speech simply uses its headroom for transients instead of loudness.

Since quality is explicitly not a goal here — the device imitates a walkie-talkie,
and those are not prized for fidelity — the right move is to **spend that crest
factor deliberately**, which is exactly what handheld radios and amateur-radio
speech processors do.

**Design: a `voice_gain` stage on the playback branch**, user-adjustable
alongside the volume (§6.3.1), applying digital make-up gain followed by a hard
limiter. Clipping is the intended effect, not a side effect.

Measured expectation, so this is not oversold: on a synthetic 10 dB-crest
signal, hard clipping alone bought **+2.6 dB at ×2 and +3.9 dB at ×8** — real,
but bounded and sharply diminishing, because clipping only flattens peaks. Real
speech at 14–18 dB crest has more to give, but the honest ceiling for
clipping alone is a handful of dB.

**To go further, compress rather than clip** — raising the quiet parts gains far
more RMS per dB of peak than squashing the loud ones. In the GStreamer pipeline
(§6.2), in increasing order of cost:

| Stage | Element | Notes |
|---|---|---|
| Make-up gain + limiter | `audioamplify amplification=N clipping-method=clip` | Cheapest; `clipping-method` must be `clip`, since the default wraps and would sound catastrophic |
| Compressor | `audiodynamic mode=compressor characteristics=soft-knee` | `gstreamer1.0-plugins-good`, modest cost, the real win |
| Voice AGC | `webrtcdsp gain-control=true` | Purpose-built for speech, but `plugins-bad` and the heaviest on ARMv6 — measure before adopting |

Start with gain + limiter because it is nearly free, add `audiodynamic` if that
is not enough, and treat `webrtcdsp` as a last resort on this CPU.

The bring-up tool exposes this as `--gain-sweep`: it records three seconds,
reports peak/RMS/crest, then replays at ×1 to ×8 showing what fraction of
samples clip at each step, and stores the chosen `playback_gain`.

### 6.4 Browser media — selectable transport mode

Browser WebRTC media is UDP and cannot traverse the Cloudflare proxy, so the
browser must reach Janus directly. There are two ways to let it, and since
different deployments of a published project will want different answers, the
mode is an **admin setting** rather than an architectural decision:

| `browser_voip_mode` | Media path | Public IP disclosed? |
|---|---|---|
| `off` | — | no |
| `wireguard` *(recommended default)* | Browser's OS tunnel → `wg0` → Janus | **no** |
| `plain_rtp` | Browser → public IP:UDP range → Janus | yes, to authenticated users |

The modes are **mutually exclusive, not a fallback chain.** It is tempting to
let Janus gather on both interfaces and let ICE pick the winner — but then the
public IP is in every SDP, which destroys the entire point of tunnel mode. So
the mode drives Janus's ICE configuration:

- `wireguard` → `ice_enforce_list = "wg0"`. Janus gathers candidates on that
  interface **only**, so the public IP *cannot* appear in the SDP. This is a
  hard guarantee from Janus, not a convention we have to maintain.
- `plain_rtp` → enforce the public interface, with `nat_1_1_mapping` set to the
  static IP.

Changing the mode rewrites `janus.jcfg` and restarts Janus, which drops any call
in progress. It is a deployment setting, not a hot toggle, and the admin console
says so.

#### 6.4.1 Browser VoIP over WireGuard

The browser has no WireGuard of its own, but the user's **operating system**
does, and the routing table is all that's needed: with `10.8.0.0/24` routed over
`wg0`, the browser's WebRTC media to Janus at `10.8.0.1` goes through the tunnel
with no browser involvement at all. Signalling stays on Cloudflare WSS.

Design details that matter:

- **Split tunnel, always.** `AllowedIPs = 10.8.0.0/24` only. The user's ordinary
  browsing is untouched, which is the difference between "a toggle I'll accept"
  and "a VPN I refuse to install".
- **One peer per *device*, not per account.** WireGuard tracks a single endpoint
  per public key, so the same config active on a phone and a laptop makes the
  two fight over the peer. The client console therefore lets an account add,
  name and revoke several devices ("Pixel", "MacBook"), each with its own
  keypair and tunnel IP.
- **QR-code onboarding.** The WireGuard mobile apps import a config by scanning
  a QR, so mobile setup is: install app → scan → toggle. That is genuinely
  within reach for a grandparent; desktop needs an installer and admin rights,
  which is the harder case. Both the `.conf` download and the QR are served from
  the client console, alongside a short illustrated tutorial per platform.
- **ICE works even with Chrome's mDNS obfuscation.** Chrome replaces local host
  candidates with `.local` mDNS names unless the page holds media permission.
  It does not matter here: Janus learns the browser's real tunnel address from
  the source of the inbound STUN connectivity check (a peer-reflexive
  candidate), and a voice page has microphone permission anyway.
- **Key generation is server-side**, and that is a real if modest trade: the
  server mints the keypair, hands over the config once, stores only the public
  key and does not retain the private key. Generating it in-browser via WebCrypto
  X25519 is possible but the user would have to paste it into a config by hand,
  which trades a small trust assumption for a large usability cost. (This is how
  VPN portals generally work.)
- **Dynamic peer management is required**, since accounts and their devices come
  and go: the server runs `wg set wg0 peer <pubkey> allowed-ips <ip>` and
  allocates from an IP pool, with no restart and no dropped calls.

  **This couples OPEN-1 to OPEN-2**: live peer management is simple when
  WireGuard sits beside the server (shared netns or a tiny privileged sidecar)
  and awkward when it terminates on the OpenWRT VM, which would then need its
  own authenticated API for the server to call. It is an argument for the
  co-located default.

Honest caveats: the user must remember to switch the tunnel on before talking
(the client console detects reachability and says so plainly), and this is the
one feature that asks a non-technical relative to install software.

#### 6.4.2 Plain-RTP mode and the firewall webhooks

When `plain_rtp` is selected, the admin console reveals a panel explaining that
the RTP port range must be reachable, and offers **two generic webhooks** — one
on session start, one on session end — so the firewall can be opened per client
without bipbox knowing anything about OpenWRT:

| Field | Notes |
|---|---|
| URL | **Jinja template too** — many router APIs are `GET /open?ip={{ CLIENT_IP }}` |
| Method | GET / POST / PUT / DELETE |
| Headers | key/value map, for tokens |
| Auth | none / basic / bearer |
| Allow invalid TLS | explicit toggle, for routers with self-signed certs |
| Body | Jinja template |
| Timeout, retries | defaults 5 s, 2 |
| **Test** | renders the template with sample values and shows the real request and response |

That test button is what makes this feature usable instead of maddening, so it
is part of the first implementation, not a nicety.

Template variables: `EVENT` (`session_start`/`session_end`), `CLIENT_IP`,
`CLIENT_ALIAS`, `CLIENT_LOGIN`, `ACCOUNT_ID`, `CHANNEL_SLUG`, `SESSION_ID`,
`TIMESTAMP` (ISO-8601), `TIMESTAMP_EPOCH`, `EXPIRES_AT`, `RTP_PORT_START`,
`RTP_PORT_END`, `USER_AGENT`.

Three hardening requirements, because this feature turns an HTTP request into a
firewall change:

1. **`CLIENT_IP` must come from a trusted proxy only.** Behind Cloudflare it is
   `CF-Connecting-IP`, and it is honoured *only* when the peer address is in
   Cloudflare's published ranges. Telex's `_real_ip()` takes the first
   `X-Forwarded-For` entry unconditionally — ported as-is, a user could spoof
   the header and have your firewall opened for an address of their choosing.
   This is the most security-sensitive line of code in the project.
2. **Templates render in a Jinja `SandboxedEnvironment`**, with variables
   JSON-escaped. The templates are admin-authored, but the admin console is
   precisely what we protected with TOTP, so it should not also be a code
   execution primitive.
3. **Expiry is authoritative; `session_end` is best-effort.** Browsers close
   without logging out, so a rule that only closes on a session-end webhook
   leaks open rules forever. `EXPIRES_AT` is passed so the firewall sets its own
   timeout, the session renews it while the page is alive, and the session-end
   hook is an early close rather than the mechanism.

Final caveat worth stating in the UI: on mobile carriers (CGNAT) and in offices,
`CLIENT_IP` is shared by many subscribers, so "open for the client's IP" is a
much weaker control than it sounds.

A fourth mode — **coturn relaying on 443/TLS** — is documented as a future
option for people who can do neither, and is not in v1.

### 6.5 WireGuard: embedded, with a tunable subnet

**Decided: WireGuard runs inside the server deployment** (a container sharing
the server's network namespace, so `wg set` works without a privileged sidecar).
The whole stack is one `docker-compose.yml`, which is what makes it publishable,
and live peer management for browser clients (§6.4.1) stays trivial.

One non-standard high UDP port, no DNS record, and **no port knocking** —
WireGuard is already silent to unauthenticated packets, which is what knocking
only pretends to achieve.

#### Subnet choice

You're right that this must be tunable, and the default should not be in
`10.0.0.0/8` at all. Three ranges are poor defaults for distinct reasons:

- **`10.x`** — your own network uses it extensively, and so do many others.
- **`172.16/12`** — Docker allocates its bridge networks from `172.17`–`172.31`,
  and we are *running in Docker*.
- **`192.168.x`** — almost every client's home LAN. A split-tunnel route that
  collides with the user's own network breaks their internet, not just bipbox.

→ **Default `100.64.42.0/24`**, inside RFC 6598 CGNAT shared space — the same
reasoning (and the same range) Tailscale uses, precisely because it collides
with neither corporate `10/8` nor home `192.168/16`. Set by `WG_SUBNET`.

A `/24` rather than something larger keeps the client-side route footprint as
small as possible. Note that the subnet is **deploy-time**: changing it reissues
every peer config, device and browser alike, so it is documented as a decision
to make once at install.

A monitoring note that follows from WireGuard's silence: **do not point an
Uptime Kuma TCP or ping monitor at the WireGuard port.** It will always report
down, correctly — the port does not answer unauthenticated packets by design.
Monitor peer handshake ages instead (§13).

---

## 7. Telex (printing)

### 7.1 Rendering and dithering

Per-device `paper_cols` / `paper_dots` (Q17), defaulting to 42 / 576 for your
two 80 mm printers. The compose UI renders at the **recipient's** width, and
warns when a multi-recipient send mixes widths.

On your point about the 1-bit threshold: you were right for the content you were
testing. Threshold and dithering are better at *different* things, so we pick
per source rather than globally —

| Source | Default | Why |
|---|---|---|
| Canvas drawing | **threshold** | Flat fills and clean lines; dithering would add noise to art that is already 1-bit in spirit. |
| Uploaded photo | **Floyd–Steinberg** | Continuous tone; threshold crushes it to blobs. |

…with a manual toggle, and `Message.image_mode` persisted so a reprint is
identical to the original.

### 7.2 Upload limits (Q18, Q21)

You asked for the distinction, and it's two separate limits:

| Stage | Limit |
|---|---|
| **Accepted from the browser** | generous — 25 MB / 50 MP. Nobody should pre-resize a phone photo. |
| **Resized server-side** | to `paper_dots` wide, then dithered |
| **Delivered to the device** | ~600 kB cap, as today — but it is now the *output* of resizing, so it can't be hit by accident |

Text stays at 500 characters (≈ 12 lines at 42 columns — a sensible ticket).
Preview is **generated server-side and returned as the dithered bitmap**, so the
on-screen preview is pixel-identical to the print rather than an approximation.

### 7.3 Queue

The server is the queue (Q19); `Delivery.status` follows
`pending → delivered → printed | failed`. The device keeps a small local spool
for received-but-not-yet-printed messages, retries every 30 s, and replays after
a reboot or a paper jam. Printer detection, the `usblp` blacklist, the udev
rules and the ESC/POS layout port directly from telex — that code was hard-won
and works.

---

## 8. Security

| Surface | Protection |
|---|---|
| `/admin` | Argon2id + **TOTP**, single admin account (Q15), server-side session, escalating fail2ban, optionally Cloudflare Access |
| `/{channel}` client login | Argon2id, hard fail2ban (telex's ladder: 3/15 min → 1 h, 5/1 h → 72 h, 7/48 h → permanent) |
| Device WebSocket | UUID + 190-bit secret, HMAC-SHA256 verification, **soft** rate limiting — log and alert, never a permanent ban (F4.3) |
| Media plane | WireGuard for devices; see **[OPEN-1]** for browsers |
| Janus admin API | localhost only, never exposed |
| Alerts | SMTP **and** ntfy (Q44): permanent bans, account locks, device offline > N minutes |

Anonymous sending is **gone** (Q13) — every human has an account. That removes
telex's "send password" concept entirely.

---

## 9. Device provisioning and image

### 9.1 `bipbox.conf` on the boot partition (Q25)

Plain `key=value` on the FAT32 partition, editable from any OS without mounting
ext4:

```ini
wifi_ssid=…
wifi_psk=…
wifi_country=FR
hostname=bipbox-arthur
server_url=https://…
device_uuid=…
device_secret=…
```

Read at first boot, applied, then the secrets are blanked in place (the file
stays, so it's obvious it was consumed). A box can thus be fully provisioned by
editing one file on the card — no keyboard, no screen, no SSH.

### 9.2 First boot (Q35)

`bipbox-firstboot.service`, oneshot: generate the UUID if absent → set hostname
(default `bipbox-XXXX` from the UUID, Q24) → regenerate SSH host keys → expand
the filesystem → apply `bipbox.conf` → print the setup ticket (IP, hostname, AP
SSID `bipbox-XXXX`, local-console password, QR code) → enable the services.

### 9.3 Network states

NetworkManager/nmcli, DHCP only (Q26). On boot: try known networks for 120 s →
on success, `wlan0` station mode; on failure, AP `bipbox-XXXX` on 192.168.4.1
with the console open for setup. mDNS via avahi as `<hostname>.local`.

Telex's hotspot path is rewritten, not ported — it was dead code (F4.1).

### 9.3a Storage: assume the card will be abused

**Two microSD cards failed during bring-up**, one of them taking an evening to
diagnose because a dead card is indistinguishable from dead hardware until you
read it on another machine. Boxes that children power-cycle will keep doing
this, so the design assumes it.

**The real fix is a read-only root filesystem** — Raspberry Pi OS provides it
via `raspi-config` → Performance Options → Overlay File System. Normal
operation then never writes to the card, so an unclean shutdown *cannot*
corrupt it, and journald goes to RAM.

That has one consequence to design for rather than discover: **the calibration
(§3.6), the device config and the print spool all need somewhere writable.**
The overlay would silently discard them at reboot. So the layout is overlay
root plus a **small dedicated rw partition** mounted for `/etc/bipbox` and the
spool — not the overlay.

Card guidance, from the failures:

- **Buy a known brand from a first-party seller.** The card that failed was
  no-name and may never have had its claimed capacity. Counterfeits fail
  exactly this way: fine at first, then silently stop storing sectors.
- **Verify before building on it**: `f3probe --destructive --time-ops /dev/sdX`.
- **32 GB.** Smaller cards are often old stock with poorer controllers and less
  spare area for wear levelling.
- **Write endurance is not the constraint.** This box writes tens of megabytes
  a day; any genuine card survives that for decades. Endurance-branded cards
  are reasonable but are not what prevents the failure seen here.
- **Keep a spare card flashed with the golden image.** It turns a dead card
  from an evening into a sixty-second swap.

### 9.4 Image build (Q34)

**pi-gen** in Docker, producing a versioned `.img.xz`: Raspberry Pi OS **Lite
Bookworm armhf** (Q33 — ARMv6 means 32-bit only). Golden-image `dd` is dropped.

Updates: **no auto-update** (Q36). A "check for update" button in the local
console queries the public GitHub releases API and applies on explicit
confirmation. The repo is public, so no token ever sits on an SD card.

### 9.5 Local console (Q22)

Flask on port 80. Read-only status page open; **every write needs the local
admin password**, generated at first boot and printed on the setup ticket. In
AP-mode first-run it is necessarily open, which is the one unavoidable window.

Exposes: WiFi (scan/add/remove), hostname, server URL + device credentials,
printer settings + test print, VoIP volume, bip on/off + frequency + volume,
reprint ticket, check for update, logs.

---

## 10. Internationalisation (Q41)

FR **and** EN, which rules out my earlier "no i18n framework" line. But Babel
or gettext is heavier than this needs.

→ **Decided: one flat JSON catalogue per locale** (`locales/fr.json`, `locales/en.json`),
loaded server-side for template rendering and served to the browser for the JS
strings — a single source of truth, no extraction toolchain, no build step.
Locale from `Accept-Language`, overridable by a switcher persisted in a cookie.

Code and comments in English throughout. Start on telex's amber/green phosphor
theme; you'll likely replace it with something matched to the bipbox logo, so
colours and fonts live in CSS custom properties from day one to make that a
restyle rather than a rewrite.

---

## 11. Repo

```
bipbox/
├── server/          # FastAPI app, Dockerfile, docker-compose.yml
├── device/          # bipboxd daemon + Flask local console
├── image/           # pi-gen config, first-boot, systemd units
├── docs/            # context, architecture, specs, hardware notes
└── CAD/             # KiCad + FreeCAD (you commit these yourself)
```

`git init` as a fresh public repo (Q37). `.gitignore`: `telex/` (reference only,
deleted once the port is done), `.CAD_orig/` (dead, kept locally for
reference), `*.FCBak`, `__pycache__/`, `.env`, `server/data/`. KiCad sources and
exported PDF/STEP are committed; `.FCStd` via git-lfs (Q38).

Ported telex code carries attribution in its commit message.

---

## 12. Phasing (Q45, with Q43 folded in)

| Phase | Contents |
|---|---|
| **0a** | **`wiring_test.py`** (§3.5) — standalone HAT bring-up tool. No dependency on anything else, so it ships first and unblocks hardware iteration immediately. |
| **0b** | **VoIP spike** — Janus + AudioBridge in Docker, 8 kHz PCMU room, Pi joins via GStreamer over WireGuard. Measure CPU and mouth-to-ear latency with 2–3 participants, then compare 16 kHz Opus. Gates the whole media design. |
| **1** | Foundations — repo, server skeleton (channels/devices/accounts, admin + TOTP), `bipboxd` skeleton with LEDs/buttons/SPI and `--fake-hardware` so it runs on your Mac |
| **2** | Telex — printer detection, ESC/POS layout, drawing/photo + dithering, queue + receipts, client send page |
| **3** | Telegraphy — WS events, orange LED, local bip, web button |
| **4** | Local console + WiFi/AP + `bipbox.conf` |
| **5** | VoIP — device audio, Janus orchestration, half-duplex PTT, **and browser VoIP** (no longer v2, since AudioBridge makes browsers native participants) |
| **6** | Image — pi-gen, first boot, flashing docs |

Phase 0 is new and goes first: it is the only part that can invalidate an
architectural choice, it needs no bipbox code at all, and you have the hardware
on hand.

---

## 13. Observability — Uptime Kuma

You run Uptime Kuma on a VPS, so health is exposed in the shape Kuma consumes
best: **HTTP status codes doing the work**, so each monitor needs no JSON query.

| Endpoint | Auth | Returns |
|---|---|---|
| `GET /health` | none | `200` + `{"status":"ok"}`. Liveness only, deliberately cheap — no DB hit. |
| `GET /health/ready` | none | `200` when DB and Janus both answer, `503` otherwise |
| `GET /health/device/{alias}` | token | `200` when that box is online, `503` when not — **one Kuma monitor per bipbox**, giving a per-box uptime graph for free |
| `GET /health/detail` | token | full JSON tree, for a Kuma "Json Query" monitor or for eyeballing |

`/health/detail` reports, each with its own `ok` flag: database, Janus (via its
API), WireGuard peers with **handshake age** per peer, every device
(`online`, `last_seen`, `queue_depth`, `printer_ok`, `fw_version`), pending and
failed deliveries in the last 24 h, image-store free space, and active bans.

Three rules for these endpoints:

- The token is a dedicated `MONITOR_TOKEN`, **not** the admin session and
  **not** behind TOTP — Kuma cannot do TOTP. It is read-only and grants nothing
  else.
- They are exempt from the fail2ban ladder, or a monitoring blip would ban your
  VPS.
- `/health` must not touch the database, so that "the app is up" and "the
  database is healthy" stay separately diagnosable — which is the entire point
  of having both it and `/health/ready`.

Per-device alerts (Q44) stay in the server via SMTP and ntfy; Kuma is the
outside-in view, deliberately duplicating it, since a server that is wedged
cannot alert on itself.

Prometheus `/metrics` is not included — Kuma does not scrape it. Easy to add if
Grafana ever appears.

---

## 14. Open decisions

**None.** All resolved as of 2026-10-03:

1. ~~Browser media vs. public-IP disclosure~~ → `browser_voip_mode` setting with
   `off` / `wireguard` / `plain_rtp`, the last carrying generic firewall
   webhooks (§6.4). Default `wireguard`, which discloses nothing.
2. ~~Where WireGuard terminates~~ → embedded in the server deployment, subnet
   tunable via `WG_SUBNET`, default `100.64.42.0/24` (§6.5).
3. ~~I18n approach~~ → flat JSON catalogue per locale (§10).
4. ~~SQLite vs Postgres~~ → SQLite only, kept portable via Alembic, no
   backend-specific SQL, and an async driver (§4.2).

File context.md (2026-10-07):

# Bipbox

## Intro

I designed a device/game for my son and grandson. I called it `bipbox`.

### Features
* **Telex**: One can go to a secured web-page and send a text message and/or a drawing/picture to the child. It is printed on a thermal printer.
* **Telegraphy**: On each device there is a LED and a pushbutton. When one child push the button on his box, it lights-up the LED on the other child’s.
* **VoIP**: Each box comes with a shoulder speakermic (with a PTT button). When one child press PTT and talk in his mic, his voice is played through the other child’s speaker.

### Hardware
In each box, there is:
* One MeanWell RS15-5 power supply
* One raspberry-pi zero w (2017)
* One Hub 4 USB from ZERO4U (specs in the appendices)
* One external USB sound card from UGREEN (specs in the appendices)
* One homemade HAT (see details after)
* One ESC/POS thermal printer (either a PRP-250 which is seen as a serial-over-usb device (`/dev/ttyACM*`) or a `Epson TM-T20II` (seen as a USB device))

## Hardware Specs

### I/O

On the top panel, there are 5 areas:
* System:
  * Power button (a simple pushbutton to power-up the Pi after a soft shutdown, and to trigger a soft shutdown)
  * Raspberry-pi activity LED (3mm low current green)
  * WiFi status LED (5mm blue)
* Power:
  * Power status LED (5mm red)
* Telex:
  * Telex status and activity (5mm green)
* VOIP:
  * 3.5mm TRRS jack for the shoulder speakermic
  * VOIP status and activity LED (5mm green)
* Telegraphy:
  * Incoming LED (5mm orange)
  * Pushbutton

On the back panel:
* C14 socket with integrated switch	and fusebox

### Homemade HAT

You can find the schematics, PCB, etc. in [./CAD/KiCAD](./CAD/KiCAD).

* Power:
  The hat distributes power from the `RS15-5` to:
  * The Pi
  * The 74HC595N that drives the LEDs (more on that later)
  * The USB hub (through its JST connector)
  I placed capacitors here and there on the power lines.
* LEDs:
  * The 74HC595N (SRCLK on Pi’s SPIO.SCLK/GPIO11, SER on SPIO.MOSI/GPIO10, RCLK on SPIO.CE1/SPIO7, SRCLR on 5V and OE on ground) drives:
    * The telegraphy LED (through a 180 ohm resistor, QC)
    * The VoIP green LED (through a 300 ohm resistor, QD)
    * The telex green LED (through a 300 ohm resistor, QE)
      (NOTE: QD vs QE is set by how the LED harness was crimped, not by the PCB -- both are 300 ohm into adjacent pins of J5. Measured on box A; discover per box.)
    * The Wi-Fi blue LED (through a 180 ohm resistor, QF)
  * The power LED is directly connected to the 5V power line through a 180 ohm resistor.
  * The low-current green LED is connected to GPIO26 through a 1k resistor
* Pushbuttons:
  * Power: directly between GPIO3 and ground
  * Telegraphy: between GPIO2 and ground, with a debounce circuit (10k resistor, 1k resistor and 2.2uF capacitor to ground in between)
  * PTT: to GPIO23. There are two variations of the wiring depending on whether the speakermic has a ring dedicated to the PPT switch on the TRRS or if we have to detect a voltage on the mic’s ring. More on that below.
* Audio:
  * The hat takes signals from the speakermic’s TRRS jack and routes it to two TRS jacks that plugs in the sound card.
    The board has two possible wirings (using jumpers, and by soldering or not some components):
    * Wiring 1 (for speakermics with a ring dedicated to PTT):
      * Tip: to the sound card’s speaker jack’s tip (through a 22ohm 1W resistor - possibility to solder a 47ohm resistor in parallel to lower the signal) - (sleeve is grounded)
      * Ring 1: To the sound card’s mic jack’s tip (sleeve is grounded)
      * Ring 2: To GPIO23
      * Sleeve: to ground
    * Wiring 2 (for speakermics with a shared mic/PTT):
      * Tip: to the sound card’s speaker jack’s tip (through a 22ohm 1W resistor - possibility to solder a 47ohm resistor in parallel to lower the signal) - (sleeve is grounded)
      * Ring 1: not wired
      * Ring 2: To the sound card’s mic jack’s tip (sleeve is grounded) through a 1uF capacitor.
        Also, we have a 10k resistor going to both a 100nF capa and a 2N700’s gate. The 2N7000’s source (and the capa’s other pin) are grounded and the drain goes to GPIO23
      * Sleeve: to ground

## Requirements

### I/O

* LEDs:
  * The low-current green led should reflect the pi’s activity (like its embedded LED)
  * The blue LED (74HC595N’s QF) should:
    * Be off when wifi is down
    * Blink slowly when looking for Wi-Fi
    * Blink in a `. . _ . . _ . .`… pattern (short, short, long, … repeated) when in AP mode (more on that later)
    * Blink fast when connecting to Wi-Fi
    * Be on (steady) when connected to Wi-Fi
  * The first green LED (telex, QD) should:
    * Be off when telex client is down
    * Blink slowly when connecting to the telex server
    * Be steady when connected to the telex server
    * Blink fast when receiving and printing a telex
  * The second green LED (VoIP, QE) should:
    * Be off when VoIP client is down
    * Blink slowly when connecting to the VoIP server
    * Be steady when connected to the VoIP server
    * Blink fast when receiving and/or sending audio
  * The orange LED (telegraphy, QC) should:
    * Have a quick blink every 2 seconds when telegraphy client is down
    * Blink slowly when connecting to the telegraphy server
    * Be off when connected to the telegraphy server EXCEPT while someone else in the same channel is pressing the telegraphy button.
* Audio:
  * A « bip » is emitted as long as someone else in the same channel is pressing the telegraphy button (can be turned on and off, volume and frequency can be changed from the local management console)
  * Everything broadcasted in the VoIP channel (except « loopback » ) is played on the speaker (volume can be changed from the local management console)
* Printer:
  * As soon as we receive a message, it is printed
  * If printing fails, it is queued for later and we try every 30s
  * If we got messages while the system was down, we print it at startup

### Management

* AP mode:
  When the Pi starts, it should look for known Wi-Fi networks (ideally we should be able to store Wi-Fi creds in a text file on the SD card). If it finds one, it connects to it. If it does not (or cannot connect) it should create an access-point called « bipbox » that we can connect to to do the setup.
* The Pi exposes a local management console (web).
  It advertises itself as `<<hostname>>.local` (by default: `bipbox.local` using mDNS.
  One can connect to the management console to tune:
  * The WiFi and networks: manage what wifi the Pi can connect to (add, remove, scan, …), maybe the addressing (static, DHCP, ...).
  * The hostname
  * The remote server(s?) address and credentials.
  * The printer settings (with a test feature).
  * The VoIP settings (volume, ...)
  * Anything that we think would be worse being tunable.

### Server

The server is self-hosted as a docker-compose and is designed to be exposed to the Internet through Cloudflare proxying.

* Admin console:
  The admin console should have strong security. Ideally a strong password with strong fail2ban + TOTP.
  It is accessible at `<<server-address>>/admin`
  It is used for:
  * Managing channels
    A channel is a group of bipboxes/owners. Bipboxes in the same channel can talk in VoIP and do telegraphy together.
  * Managing devices (bipboxes)/owners.
    Each bipbox should have a unique UUID. It must be part of a channel.
    It has a unique and strong authentication mechanism (that we can enter in the bipbox’s local management console) such as a long ID and key couple or even mTLS.
    It has an alias (such as the owner surname).
  * Managing web clients.
    We can create accounts for people that do not have a bipbox but can use a web interface to, at least, send Telex and, if possible, join the VoIP and telegraphy channel.
    Client accounts are attached to a channel. We can choose if they can communicate with the whole channel or only some devices.
    They each have a client ID and a password that should be strong.
* Client console:
  Clients can go to `<<server-address>>/<<channel>>` or `<<server-address>>/<<channel>>/<<device>>`.
  They are required to login. A hard fail2ban is applied (we are talking about an interface that can be used to communicate with children).
  From there, they can:
  * Manage their account (change password, ...)
  * Send telex to one or multiple recipients in the channel depending on the client’s permissions. Telex can be a text (through a textarea mimicking the printed result), a drawing (through a « paint-like » interface in the webpage) or a picture (converted to be printed in black and white).
  * Participate in the VoIP channel
  * Do telegraphy (a simple button + a light)

### Stack

We will use Python/Flask as much as possible.

### Embedding

Last step will be to produce a ready-to-flash (on a SD card) Raspberry Pi OS minimal image so we can flash a card with a bipbox-ready system and fire it up without having to tweak file, plug a keyboard, screen, or SSH to it.

# Appendices

## USB sound card specs

Raspberry-pi compatible

Brand Name	UGREEN
Hardware Interface	USB
Audio Output Mode	Stereo
Platform	Linux, Mac, Mac OS X, PlayStation 4, Windows 10
Hardware Platform	ARM
Model Name	UGREEN External USB Soundkarte
Surround Sound Channel Configuration	2.0
Signal-to-Noise Ratio	90 dB

You can plug in mic and headset at the same time, perfect for talking with friends while playing games, making videos on YouTube. The microphone input is in MONO. Note: The microphone jack only supports TRS jack (3-pole), does not support TS (2-pole) and TRRS (4-pole).

Universal Compatibility: This external USB sound card is compatible with PS5, PS4, PS4 Pro, desktop PC, laptop, Microsoft Surface, gaming headset, speaker, microphone, etc. Note: This USB jack adapter does not support PS3, Wii, Wii U, Xbox, TV, car.

No need to install additional drivers, just plug this USB audio adapter into the USB port and it will be automatically recognized by PC immediately. This USB sound card converter is compatible with multiple systems and supports Windows 11/ 10/ 8.1/ 8/ 7/ Vista/ XP, Mac OS, Chrome OS, Android and Linux systems. The driver must be installed for Linux systems.

This external stereo adapter has a built-in high-performance DAC smart chip with a sampling rate of up to 16bit/48kHz, which can prevent electromagnetic interference and reduce background noise. Oxygen-free copper cable ensures optimal sound quality and achieves stereo effect, the sound is clearer and more precise than the other USB sound card stick.

This USB audio to jack adapter is designed with an extension cord (15 cm). The body of the cord is flexible and can be bent and pulled at will without blocking the other USB plugs next to it, making it more practical than other USBs. It is small and does not take up space when carrying it, making it convenient to take along.

## Hub specs

This is a 4-port USB hub for Raspberry Pi Zero, and it can be mounted to Raspberry Pi Zero back-to-back. The 4 pogo pins on the back will connect the PP1, PP6, PP22 and PP23 testing pads on Raspberry Pi Zero, hence no soldering will be needed.

This is a 4-port USB hub for Raspberry Pi Zero, and it can be mounted to Raspberry Pi Zero back-to-back. After mounting this USB hub to your Raspberry Pi Zero, it immediately has 4 USB ports that could transfer data in USB 2.0 high-speed. The 4 pogo pins on the back will connect the PP1, PP6, PP22 and PP23 testing pads on Raspberry Pi Zero, hence no soldering will be needed.

The USB hub will take power directly from your Raspberry Pi Zero, so you don’t need to power the USB hub separately. However you can use the JST XH2.54 connector on board as the alternative power input port.

The blue LED on board works the power indicator, and will lights up when power is connected.

Each USB port has a dedicated white LED as transaction indicator, and a dedicated electrolytic capacitor to help stabilizing the output voltage.

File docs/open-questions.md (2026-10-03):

# Bipbox — Open questions before implementation

Status: **answered 2026-10-03** — superseded by [`architecture.md`](./architecture.md). Kept for the record.

Based on a full read of `context.md` and the `telex/` codebase (server: FastAPI +
SQLModel + SQLite; client: Python daemon + Flask portal; deploy: systemd +
golden-image scripts).

Each question has a **→ recommendation** so you can answer "defaults except Q7, Q12, …".

---

## Decisions taken (2026-10-02)

- **D1 (was Q1) — Stack:** FastAPI + SQLModel + SQLite on the server (port of
  telex), Flask for the Pi's local console. "Python/Flask" reads as "Python,
  Flask where it fits".
- **D2 (was F1) — PTT is on GPIO23.** The `GPIO3` references in `context.md`
  §Audio are a typo. Power button keeps GPIO3 (wake-from-halt preserved). GPIO23
  uses the Pi's internal pull-up for both the bare-switch and 2N7000 wirings.
  → `context.md` needs correcting.
- **D3 — Public IP must never appear in public DNS.** Audio endpoint details are
  pulled by the box from the bipbox server *after* authentication (over the
  Cloudflare-proxied HTTPS link), never published. Web clients stay entirely on
  the proxied HTTPS path.
- **D4 (was Q46) — Process:** one architecture document covering the whole
  system (architecture, data model, wire protocol, device/server API, pin map,
  LED timings) for review, then implementation feature-by-feature.
- **D5 — VoIP goals:** minimise latency; sound quality is explicitly *not* a
  priority (mono speakermic); respect the Pi Zero W's ARMv6 budget. Off-the-shelf
  software (e.g. Mumble) is acceptable rather than a hand-rolled protocol.

---

## Part 0 — Findings you should decide on first

These are contradictions or risks I found, not questions of taste.

### F1. GPIO3 is assigned twice (blocking)

`context.md` says:

- Power button: "directly between GPIO3 and ground" (§Pushbuttons)
- PTT: "to GPIO23" (§Pushbuttons)
- But then, in §Audio, **both** wiring variants route PTT to **GPIO3**
  ("Ring 2: To GPIO3" / "the drain goes to GPIO3")

GPIO3 is special: it is the only pin that wakes a Pi from a soft halt, so the
power button genuinely needs it. PTT cannot share it. I suspect "GPIO3" in the
audio section is a typo for "GPIO23", which matches the pushbutton section — but
the board is already made, so only you can confirm what is etched.

→ **Q: which is it on the actual PCB?** If PTT really is on GPIO3, we lose
power-on-from-halt (the box would only be power-cyclable from the C14 switch) or
we lose PTT — one of the two needs a wire mod.

Note on why GPIO2/GPIO3 are attractive for buttons: they carry the Pi's only
*external* 1.8 kΩ pull-ups to 3V3, so a bare switch-to-ground works with no
software pull-up. GPIO23 has no external pull-up, but the Pi's internal ~50 kΩ
programmable pull-up is fine for both a switch and the 2N7000's open drain.

**→ Answer:** PTT goes to GPIO23, it was a typo

### F2. 74HC595 at 5 V driven by 3.3 V logic is out of spec

The HAT powers the '595 from 5 V and drives SRCLK/SER/RCLK from the Pi (3.3 V).
A **74HC**595 at Vcc = 5 V needs V_IH ≥ 3.5 V (0.7 × Vcc). The Pi tops out at
3.3 V. It usually works at room temperature and then fails intermittently when
warm — exactly the kind of bug that is miserable to chase later.

Fixes, best first:

1. Swap the chip for a **74HCT595** (TTL input thresholds, V_IH = 2.0 V) —
   pin-compatible, no board change, keeps 5 V LED drive and your existing
   resistor values.
2. Power the '595 from 3V3 instead. But then the **blue LED won't work**: Vf ≈
   3.0–3.2 V, so (3.3 − 3.2)/180 Ω ≈ nothing. Not viable without changing
   resistors and probably the LED.

Current draw check, for the record (5 V rail, all four LEDs on): orange 180 Ω ≈
17 mA, blue 180 Ω ≈ 10 mA, two greens 300 Ω ≈ 10 mA each → ≈ 47 mA, inside the
'595's 70 mA package limit. So option 1 is clean.

→ **Q: do you want to swap to 74HCT595, or ship 74HC595 and accept the risk?**

**→ Answer:** I ordered some 74HCT595N and will try to unsolder the 74HC595N to swap it. Otherwise I will have to make new boards (I have spare PCBs).
In the meantime (the 74HCT595N won’t be here before a week) I will work with the 74HC595N (my guess is that it won’t change a thing software-wise).

### F3. No RTC on the BOM

Printed tickets show a timestamp. The Pi Zero W has no RTC, so after a power cut
without internet the clock is wrong until NTP succeeds.

→ **Recommendation: the printed timestamp comes from the server** (sent with the
message), not from the Pi. Pi-local time is only used for diagnostics. Cheap,
no hardware change.

**→ Answer:** Fine by me. Sending time makes more sense than printed time moreover.

### F4. Three bugs / design choices in telex not to carry over

1. `client/wifi_manager.py:__main__` reads `conf["uuid"]`, but `config.py`
   `DEFAULTS` has no `uuid` key → `KeyError` on every boot where no WiFi is
   found, i.e. the hotspot fallback is dead. (Bipbox needs a per-device UUID
   anyway — see Q14.)
2. `server/app/main.py` has a catch-all `@app.get("/{filename}")` returning
   `client.html`. That will collide head-on with bipbox's `/{channel}` and
   `/{channel}/{device}` routes and with `/admin`. Needs explicit routing.
3. The escalating fail2ban (`rate_limit.py`) is applied to the **device** API as
   well as the public one. A box with a stale password earns a *permanent* IP
   ban after 7 tries — which, since all your boxes may sit behind one home IP,
   can brick a sibling box too. Bipbox should use a separate, softer policy for
   devices (log + alert, never permanent) and keep the harsh policy for humans.

**→ Answer:** Agree to everything.

---

## Part 1 — Stack and architecture

### Q1. Flask or FastAPI for the server?

`context.md` says "Python/Flask as much as possible". But telex's server is
**FastAPI** (+SQLModel/SQLite) — only the Pi's local portal is Flask. Bipbox
also needs persistent bidirectional connections (telegraphy, VoIP, live LED
state), which is native in FastAPI/Starlette and needs `flask-socketio` +
eventlet/gevent in Flask.

→ **Recommendation: keep FastAPI on the server** (maximum reuse of telex, native
async WebSockets) and **keep Flask for the Pi's local console** (tiny, sync,
already written). "Python/Flask" then means "Python, Flask where it fits".

Confirm, or state that Flask is a hard requirement.

**→ Answer:** Agree with you: go for FastAPI.

### Q2. One server connection or three?

The LED spec talks about "the telex server", "the VoIP server" and "the
telegraphy server" as if they were distinct, and the local console mentions
"the remote server(s?)".

→ **Recommendation: one server, one address, one credential, one persistent
WebSocket** carrying three logical channels (telex / telegraphy / audio). The
three LEDs then reflect three *service states* over that one link. Much simpler
to configure and to secure.

Confirm, or tell me you want physically separate endpoints (e.g. audio on its
own host/port).

**→ Answer:** I agree. I talked about separate servers not to close any door (if using a dedicated VoIP server for instance) but of course a single endpoint is better.

### Q3. Push instead of poll — confirm

Telex polls every 60 s. Bipbox needs instant telegraphy and "blink fast when
receiving a telex", so the box must hold a persistent connection.

→ **Recommendation: persistent WebSocket with heartbeat; messages pushed
instantly; polling kept only as a reconnect/catch-up mechanism ("give me
everything I missed") at connect time**, which also satisfies "if we got
messages while the system was down, we print at startup".

**→ Answer:** Agree

### Q4. On-device process architecture

Three features all need the same scarce resources: the SPI bus / '595 (LEDs),
the GPIOs, the sound card, the printer. Running three independent systemd
services that each poke SPI will fight.

→ **Recommendation: one supervisor daemon** (`bipboxd`) owning GPIO, SPI/LEDs,
audio and printer, running telex/telegraphy/VoIP as asyncio tasks over the
single server connection; plus **a separate Flask process** for the local
console, talking to the daemon over a Unix socket. Two services instead of five,
and no resource contention.

Any objection? (The alternative — one service per feature + an "LED broker" —
is more moving parts for no gain at this scale.)

**→ Answer:** Agree. So SPIO and USB share the same bus ?

---

## Part 2 — VoIP (the biggest decision)

### Q5. Audio transport — revised after D3/D5

Your proposal (endpoint handed out post-authentication, never in DNS) is sound
and it unlocks **UDP**, which the Cloudflare proxy could never carry. That in
turn makes latency a solvable problem rather than a compromise. Two sub-questions
follow.

#### Q5a. Hide the audio port behind WireGuard?

Keeping the IP out of DNS stops casual discovery, but public IPv4 space is
scanned wholesale regardless of DNS, so an open audio port *will* be found and
probed. **WireGuard answers this properly: it does not reply to any packet that
fails key authentication, so the port is invisible to a scanner** — it looks like
a closed/filtered port.

Proposed shape:

- Each box holds a WireGuard peer config, **pulled from the bipbox server after
  HTTPS authentication** (exactly your mechanism, with the tunnel key instead of
  a bare IP).
- One UDP port open on your static IP. Nothing else. No DNS record.
- Audio binds to the tunnel interface only, so it is unreachable from the
  internet by construction.
- Boxes get stable private addresses — which also makes debugging and future
  SSH-in far nicer.
- Cost on a Pi Zero W: WireGuard is in-kernel on Bookworm (6.1), and a ~30 kbit/s
  stream is nowhere near its few-Mbit/s ceiling. Encryption overhead is
  negligible at this rate.
- Web clients do **not** get the tunnel; they stay on the Cloudflare-proxied
  HTTPS path.

→ **Recommendation: yes, WireGuard.** It costs one `wg0` interface and gives you
a genuinely unprobeable attack surface plus per-device key revocation.

Objection to consider: it adds a provisioning step and a failure mode ("tunnel
down" is now a distinct state the VoIP LED must express).

**→ Answer:** I am not against, even if it complicates things a bit… and wireguard adds overhead to the Pi.
We should also consider using a non-standard port (even if it has very low security impact) and more importantly port-knocking (or even dynamically opening the port just for the client IPs through my firewall). My firewall is on a powerful OpenWRT VM and I can consider running a service to dynamically open the connections for the client addresses.

#### Q5b. Which audio stack? — SUPERSEDED by `voip-options.md`

**The Mumble recommendation below is withdrawn.** A proper survey of the
alternatives (see **[`voip-options.md`](./voip-options.md)**) reaches a different
conclusion: **Janus Gateway's AudioBridge plugin**, with the Pi joining as a
*plain RTP participant* over WireGuard and a GStreamer pipeline on the device.

In one line: AudioBridge **mixes server-side**, so the Pi decodes exactly one
stream forever instead of one per speaker, and it accepts **G.711/PCMU at
8 kHz** from plain-RTP participants, so the ARMv6 chip does no Opus, DTLS, ICE or
SRTP work at all — while browser clients join the very same room over native
WebRTC for free.

Mumble is rejected on measurements, not taste: its protocol is 48 kHz Opus only
and it *forwards* rather than mixes, and the talKKonnect project (Mumble PTT
radios on Raspberry Pis) reports 48 kHz Opus at **nearly 100% CPU on a
single-core ARMv6 Pi Zero**. `pymumble` also has no UDP media path at all —
TCP tunnel only, which contradicts D5.

The original Mumble analysis is kept below for the record.

<details>
<summary>Withdrawn: original Mumble-vs-custom analysis</summary>

**Mumble (`mumble-server`/murmur + `pymumble` on the Pi) — recommended**

What you get for free, all of it stuff I would otherwise be writing badly:

- A tuned **adaptive jitter buffer**. This is the single most underestimated
  piece of any voice system, and the main reason hand-rolled audio sounds worse
  than it should.
- Opus, 10/20 ms frames, genuinely low latency — Mumble's whole reputation is
  built on this.
- A native **channel** concept with ACLs that maps 1:1 onto your bipbox
  channels, plus per-user certificates, encryption, and no self-echo
  ("except loopback" comes free — Mumble never sends you your own audio).
- `mumble-web` + `mumble-web-proxy` give browser clients a WebRTC path later,
  which is most of Q43's cost removed.
- Mature, packaged, and someone else maintains the audio stack.

Costs and risks, honestly:

- **The Pi-side risk is `pymumble` on ARMv6, and it must be spiked early.**
  Mumble's protocol is 48 kHz-only, so we cannot drop to 16 kHz to save CPU, and
  Mumble does **not** mix server-side — the client decodes one Opus stream *per
  speaker*. With 2–3 boxes that is 2–3 decodes plus one encode in CPython on a
  single 1 GHz ARMv6 core. I believe it fits (`botamusique` runs on small Pis)
  but I will not claim it without measuring.
- A second identity system to provision (Mumble certs/passwords) alongside
  bipbox's. Manageable: the bipbox server creates the Mumble channel and issues
  the device's credentials, and the box pulls them with everything else.
- `pymumble` and `mumble-web` are community-maintained, not bulletproof.

**Custom UDP + server-side mixing (the fallback)**

- 16 kHz mono Opus, 20 ms frames, our own 6-byte header over the WireGuard
  tunnel; the server mixes per channel and sends each box exactly **one** stream
  to decode.
- Lowest possible CPU on the Pi (1 decode, 1 encode), lowest bandwidth, lowest
  latency, no second auth system.
- But I write the jitter buffer, packet loss handling and sequencing — and that
  is precisely where a naive implementation turns into choppy audio.

→ **Recommendation: design for Mumble, but gate it on a hardware spike** (phase
0: `pymumble` + `opuslib` on a real Pi Zero W, measure CPU and mouth-to-ear
latency with 3 simulated speakers). Keep the daemon's audio module behind a
narrow interface so the fallback is a swap, not a rewrite. If the spike shows
CPU headroom is thin, custom UDP with server-side mixing wins on the merits.

Do you agree with spiking first, or would you rather commit to one now?

</details>

→ **Recommendation: Janus AudioBridge, still gated on a hardware spike** (now
much cheaper to run: Janus in Docker + two GStreamer pipelines, no Python audio
stack to build). Measure CPU and mouth-to-ear latency on the real board at
8 kHz/PCMU, then try 16 kHz/Opus. Fallback order: Asterisk ConfBridge + baresip,
then a custom mixer. Full reasoning and sources in
[`voip-options.md`](./voip-options.md).

**→ Answer:** Agreed for Janus

#### Q5c. Room-per-channel mapping

One bipbox channel → one Janus AudioBridge room; each device → one plain-RTP
participant; each web client → one WebRTC participant in the same room. Our
server creates and configures rooms through Janus's API; the bipbox admin console
stays the only UI you touch, and Janus's own admin surface is never exposed.

→ **Recommendation: yes.** Rooms created on demand from the channel definition,
so adding a channel in the admin console needs no Janus configuration by hand.

**→ Answer:** Agree

### Q6. Half-duplex or full-duplex?

A shoulder speakermic with PTT is classically half-duplex, and the box's speaker
sits ~10 cm from its own mic — full duplex will howl without acoustic echo
cancellation (which we do not want to write for an ARMv6 chip).

→ **Recommendation: half-duplex. While PTT is held: mic streams, local speaker
is muted.** Confirm.

**→ Answer:** Half-duplex of course

### Q7. Contention: two people press PTT at once

→ **Recommendation: server mixes both** (simplest, and "everyone hears
everyone"). Alternative is first-come-wins with a "busy" indication (more
walkie-talkie-authentic, more code, and a child holding PTT could lock the
channel).

Which do you want?

**→ Answer:** server mixes both

### Q8. Does audio need to be recorded or logged?

→ **Recommendation: never recorded; only "who talked when" metadata, if
anything.** Confirm — it changes the privacy story and the admin UI.

**→ Answer:** No record. Metadata could be logged if the feature is easy to implement and should be controlled by a on/off switch in the admin console (disabled by default)

### Q9. The "bip" (telegraphy tone)

Spec says it plays as long as someone else holds their button, with
frequency/volume tunable locally.

→ **Recommendation: generated locally on the Pi** (no audio sent over the wire
for telegraphy — just a press/release event), mixed with VoIP playback via ALSA
`dmix` (the UGREEN card won't mix in hardware). Confirm, and tell me defaults
you'd like (I'd suggest 880 Hz, soft attack/release to avoid clicks).

**→ Answer:** This is exactly what I had in mind.

### Q10. Target audio latency — answered by D5, one number to confirm

Quality is settled (voice-radio is fine). Latency is the target to design
against, and it is what the Q5b spike must measure.

→ **Recommendation: aim for < 150 ms mouth-to-ear, treat > 300 ms as a failure.**
Over WireGuard/UDP to your own static IP this is realistic; it was not with
WebSockets through Cloudflare. Frame size: 20 ms (10 ms shaves latency but
costs proportionally more CPU and packet overhead on the Pi — a spike question).

Sample rate is forced to 48 kHz if we take Mumble; 16 kHz if we go custom.

**→ Answer:** Preferably < 150ms, <500ms worst case scenario (this is just a toy after all)

---

## Part 3 — Channels, devices, accounts

### Q11. Can a device belong to more than one channel?

`context.md`: "It must be part of a channel" (singular).

→ **Recommendation: exactly one channel per device** (simple mental model, and
it makes "who do I broadcast to" unambiguous). Confirm.

**→ Answer:** Yes only one channel

### Q12. Can a web client belong to more than one channel?

Same question for human accounts — e.g. a grandparent who wants to reach two
different channels.

→ **Recommendation: allow multiple channel memberships per web account**, each
membership carrying its own permissions (which devices it may reach).

**→ Answer:** If it is easy, yes, but real use cases seems very unlikely IMO

### Q13. Does telex's "simple send password" model survive?

Telex let *anyone* with a URL and an easy password (a date of birth) send a note,
with no account. Bipbox's spec replaces this with proper accounts (client ID +
strong password) at `/{channel}` and `/{channel}/{device}`.

→ **Recommendation: drop anonymous sending entirely.** It is the right call for
a channel children listen to. Confirm — it means family members each get an
account, which is more friction for them. (Middle ground available: keep a
per-device "guest link" that an admin can enable/disable and that is rate
limited hard.)

**→ Answer:** I confirm, drop it

### Q14. Device identity and authentication

Spec floats "a long ID and key couple or even mTLS".

→ **Recommendation: UUID + 32+ byte secret, bcrypt-hashed server side** (like
telex, which already works), entered once in the local console. **mTLS is a trap
here**: the Cloudflare proxy terminates TLS, so client certificates never reach
your origin unless you use Cloudflare's mTLS/Access features — extra cost and
complexity for no real gain over a long secret on an HTTPS link.

Confirm, or tell me mTLS is a hard requirement (then we need a non-proxied
hostname for device traffic).

**→ Answer:** Yes I think the long password is enough

### Q15. Admin console authentication

Telex has a single `ADMIN_API_KEY` sent in a header — not enough for what you
describe ("strong password + fail2ban + TOTP").

→ **Recommendation: single admin account, Argon2id password + TOTP (pyotp),
server-side sessions in secure cookies, the existing escalating fail2ban applied
to `/admin`, `/admin` also behind a Cloudflare Access rule if you want
belt-and-braces.** One admin user or several?

**→ Answer:** Yes for the recommendation. A single admin user.

### Q16. Can a device be moved/renamed without re-provisioning?

→ **Recommendation: yes — identity is the UUID, the alias and channel are server
side and can change at any time.** Confirm.

**→ Answer:** Yes

---

## Part 4 — Telex (printing)

### Q17. Paper width per box

Telex hardcodes `PAPER_WIDTH = 42` (80 mm). You list a PRP-250 **and** a
TM-T20II. If one of them is 58 mm, the layout and image width (384 vs 576 dots)
differ.

→ **Q: which printer in which box, and what paper width each?**
→ **Recommendation: make width a per-device setting** (auto-detected where
possible, overridable in the local console), not a constant.

**→ Answer:** Both my printers are 80mm. However, having the width as a setting is a good idea.
Keep in mind that the interface should reflect the final rendering of the printed ticket. If recipients have different paper size, at least a warning should be displayed.

### Q18. Drawings and photos

Telex already has a canvas drawing tool (fill, grayscale palette, undo, S/M/L
sizes) and photo upload, printed via PIL `convert("1")`.

→ **Recommendation: reuse as-is, but replace the 1-bit threshold with
Floyd–Steinberg dithering** — plain `convert("1")` destroys photos. Also cap
image dimensions server-side to the device's dot width.

Anything you disliked about telex's drawing UI that I should change?

**→ Answer:** I did not check it for a while but I believe it was very good.
The 1 bit threshold was to make the picture look as good as possible despite the ESC/POS limitations. If Floyd–Steinberg dithering can make better results then let’s go.
When you say cap dimensions server-side: do you mean resize server-side ? If so yes. If you mean limit what a user can upload then yes BUT with a comfortable value: a user should not have to resize regular pictures himself before uploading (of course, not talking about a 100MP tiff picture).

### Q19. Print queue durability

Spec: retry every 30 s; print what was missed at startup.

→ **Recommendation: the *server* is the queue** (telex's `Delivery` table
already models `pending → delivered → printed | failed`). The Pi keeps only a
small local spool for messages received-but-not-yet-printed, so a paper jam
doesn't lose anything and a reboot replays. Confirm.

**→ Answer:** Confirmed.
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

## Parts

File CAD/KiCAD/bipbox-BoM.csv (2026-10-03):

Reference | Value | Datasheet | Footprint | Qty | DNP | Description
C1,C3,C4 | 100n |  | Capacitor_THT:C_Disc_D7.5mm_W2.5mm_P5.00mm,Capacitor_THT:C_Disc_D8.0mm_W2.5mm_P5.00mm | 3 |  | Decouplage,Decouplage registre,Unpolarized capacitor
C2 | 470u |  | Capacitor_THT:CP_Radial_D10.0mm_P5.00mm_P7.50mm | 1 |  | Polarized capacitor
C5 | 220u |  | Capacitor_THT:CP_Radial_D8.0mm_P5.00mm | 1 |  | Condensateur faible ESR 220µF/25V
C6 | 2.2u |  | Capacitor_THT:C_Disc_D7.5mm_W2.5mm_P5.00mm | 1 |  | Debouncing capa
C11 | 1u |  | Capacitor_THT:C_Disc_D7.5mm_W2.5mm_P5.00mm | 1 |  | Unpolarized capacitor
D11 | Red LED |  |  | 1 |  | Green LED
D12 | Blue LED |  |  | 1 |  | Green LED
D13 | Gre LED1 |  | Resistor_THT:R_Axial_DIN0204_L3.6mm_D1.6mm_P7.62mm_Horizontal | 1 |  | Green LED
D14 | Gre LED2 |  | Resistor_THT:R_Axial_DIN0204_L3.6mm_D1.6mm_P7.62mm_Horizontal | 1 |  | Green LED
D15 | Yel LED |  | Resistor_THT:R_Axial_DIN0204_L3.6mm_D1.6mm_P7.62mm_Horizontal | 1 |  | Green LED
D16 | LED |  |  | 1 |  | Low Power (2mA) green LED - RPi activity light
DC-jack21,JPWR01,JPWR02,Power-switch10 |  | https://www.nidec-components.com/e/catalog/switch/cas.pdf | Button_Switch_SMD:Nidec_Copal_CAS-120A,Connector_JST:JST_XH_B2B-XH-A_1x02_P2.50mm_Vertical,Connector_Molex:Molex_KK-396_A-41791-0002_1x02_P3.96mm_Vertical | 4 |  | DC Barrel Jack (Power),JST Power in,Switch, single pole double throw,USB hub power out
J1,J4 | Conn_01x04_Pin |  | Connector_JST:JST_XH_B4B-XH-A_1x04_P2.50mm_Vertical | 2 |  | Generic connector, single row, 01x04, script generated
J2,J3,J1001,J1002 | Conn_01x03_Pin |  | Connector_JST:JST_XH_B3B-XH-A_1x03_P2.50mm_Vertical | 4 |  | Generic connector, single row, 01x03, script generated,Jack 3.5 TRS
J5 | Conn_01x06_Pin |  | Connector_JST:JST_XH_B6B-XH-A_1x06_P2.50mm_Vertical | 1 |  | LEDs JST
J6 | Conn_01x02_Pin |  | Connector_PinHeader_2.54mm:PinHeader_1x02_P2.54mm_Vertical | 1 |  | Generic connector, single row, 01x02, script generated
J11 | AudioJack4 |  |  | 1 |  | Audio Jack, 4 Poles (TRRS)
J40 | GPIO |  | Connector_PinSocket_2.54mm:PinSocket_2x20_P2.54mm_Vertical | 1 |  | Generic connector, double row, 02x20, odd/even pin numbering scheme (row 1 odd numbers, row 2 even numbers), script generated (kicad-library-utils/schlib/autogen/connector/)
JP1,JP2,JP3 | Jumper_2_Small_Open |  | TestPoint:TestPoint_2Pads_Pitch2.54mm_Drill0.8mm | 3 |  | Jumper, 2-pole, small symbol, open
JUSB12 | USB_A |  | Connector_USB:USB_A_Molex_105057_Vertical | 1 |  | USB Type A connector
Q1 | IRF4905 | http://www.infineon.com/dgdl/irf4905.pdf?fileId=5546d462533600a4015355e32165197c | Package_TO_SOT_THT:TO-220-3_Vertical | 1 |  | -74A Id, -55V Vds, Single P-Channel HEXFET Power MOSFET, 20mOhm Ron, TO-220AB
Q2 | 2N7000 | https://www.vishay.com/docs/70226/70226.pdf | Package_TO_SOT_THT:TO-92_Inline | 1 |  | 0.2A Id, 200V Vds, N-Channel MOSFET, 2.6V Logic Level, TO-92
R1,R2,R5 | 180 |  | Resistor_THT:R_Axial_DIN0204_L3.6mm_D1.6mm_P7.62mm_Horizontal | 3 |  | Resistor
R3,R4 | 300 |  | Resistor_THT:R_Axial_DIN0204_L3.6mm_D1.6mm_P7.62mm_Horizontal | 2 |  | Resistor
R6,R9,R10 | 10k |  | Resistor_THT:R_Axial_DIN0204_L3.6mm_D1.6mm_P7.62mm_Horizontal,Resistor_THT:R_Axial_DIN0207_L6.3mm_D2.5mm_P7.62mm_Horizontal | 3 |  | Debouncing pull-up,Resistor
R7,R8 | 1k |  | Resistor_THT:R_Axial_DIN0207_L6.3mm_D2.5mm_P7.62mm_Horizontal | 2 |  | Resistor
R11 | 22 |  | Resistor_THT:R_Axial_DIN0207_L6.3mm_D2.5mm_P15.24mm_Horizontal | 1 |  | Resistor
R12 | 47 |  | Resistor_THT:R_Axial_DIN0204_L3.6mm_D1.6mm_P7.62mm_Horizontal | 1 |  | Resistor
SW11,SW12 | SW_Push |  |  | 2 |  | Morse Push Button,Push button switch, generic, two pins
U2 | 74HC595 | http://www.ti.com/lit/ds/symlink/sn74hc595.pdf | Package_DIP:DIP-16_W7.62mm | 1 |  | 8-bit serial in/out Shift Register 3-State Outputs

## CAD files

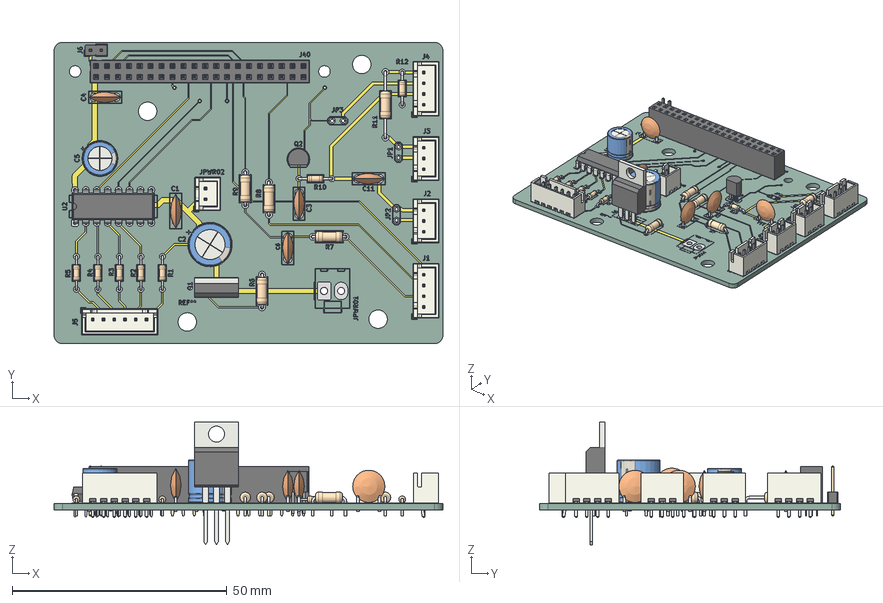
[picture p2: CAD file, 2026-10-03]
CAD/3D/MB.step
90.5 x 70.1 x 28.5 mm
PinSocket_2x20_P2.54mm_Vertical
DIP-16_W7.62mm
R_Axial_DIN0207_L63mm_D25mm_P1524mm_Horizontal
C_Disc_D75mm_W25mm_P500mm x 4
R_Axial_DIN0204_L36mm_D16mm_P762mm_Horizontal x 7
JST_B3B_XH_A x 2
PinHeader_1x02_P254mm_Vertical
R_Axial_DIN0207_L63mm_D25mm_P762mm_Horizontal x 4
JST_B6B_XH_A
CP_Radial_D100mm_P500mm_P750mm
CP_Radial_D80mm_P500mm
JST_B2B_XH_A
JST_B4B_XH_A x 2
C_Disc_D80mm_W25mm_P500mm
TO-92_Inline_Narrow
TO-220-3_Vertical
hams-telex_copper
hams-telex_pad
hams-telex_via
hams-telex_silkscreen
hams-telex_PCB

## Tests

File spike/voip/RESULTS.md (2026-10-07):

# VoIP spike — results

Fill this in as you measure. The decision rule is in `README.md` and was agreed
before any numbers existed, so the outcome is not argued after the fact.

## Server side — done

Verified 2026-10-03 on an arm64 Docker host, Janus **1.4.2**, AudioBridge
**0.0.13**:

| Check | Result |
|---|---|
| Janus builds from pinned source | ✅ |
| `audiobridge` plugin loads | ✅ 0.0.13 |
| Static rooms with `allow_rtp_participants` | ✅ accepted, no API creation needed |
| Plain-RTP join, 8 kHz room, PCMU | ✅ `payload_type` 0 assigned automatically |
| Plain-RTP join, 16 kHz room, Opus | ✅ `payload_type` 111 accepted |
| Plugin RTP ports inside the configured range | ✅ after setting the *plugin's* own `rtp_port_range` |

## Device side — to measure on a Pi Zero W

| Codec | Room rate | Others in room | TX active | Avg CPU | Peak CPU | Latency (median of 10) | Notes |
|---|---|---|---|---|---|---|---|
| PCMU | 8000 | 1 | no | | | | |
| PCMU | 8000 | 1 | yes | | | | |
| PCMU | 8000 | 2 | yes | | | | |
| Opus | 16000 | 1 | yes | | | | |
| Opus | 16000 | 2 | yes | | | | |

CPU is a percentage of **one** core — the Pi Zero W has exactly one.

### Jitter buffer

The `rtpjitterbuffer latency` default in the spike is 60 ms. If audio is clean,
try lowering it; if it is choppy, raise it. Record what you settle on, because
it is the single largest tunable contributor to latency.

| latency (ms) | Audio quality | Measured mouth-to-ear |
|---|---|---|
| 60 | | |

### Observations

<!-- Anything surprising: dropouts, clock drift, distortion, thermal effects
     after a few minutes, behaviour when the Pi's WiFi is weak. -->

## Decision

<!-- Confirmed / tight / fall back — per the rule in README.md. -->

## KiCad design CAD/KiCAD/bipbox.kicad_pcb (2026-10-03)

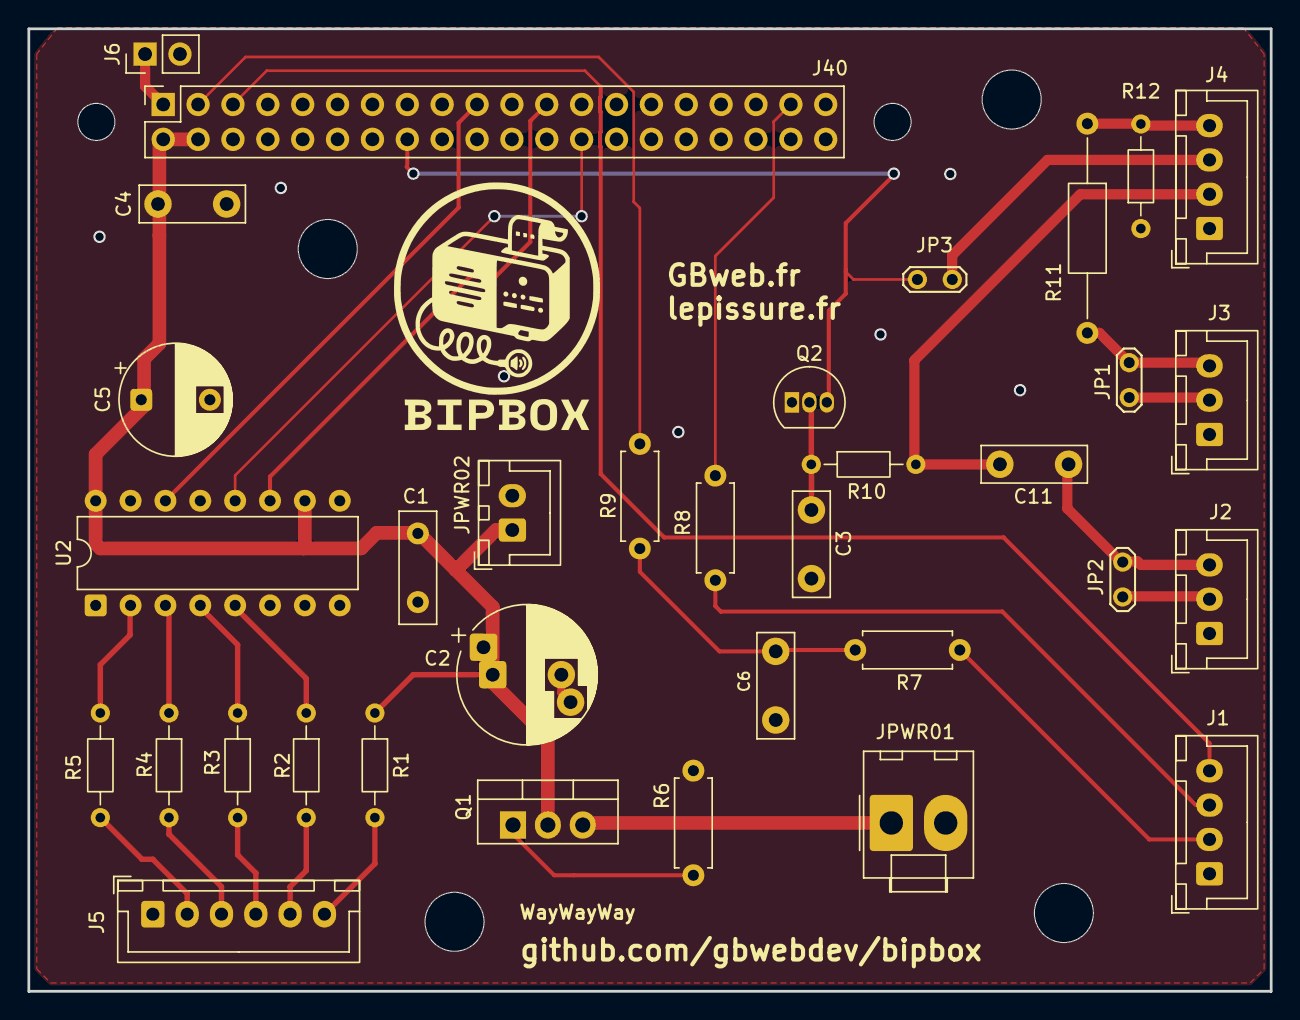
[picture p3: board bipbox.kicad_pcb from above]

Board: 2 copper layers, 90.5 x 70.1 mm, 36 parts (0 on the bottom side), 32 nets.

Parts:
C1: 100n; C_Disc_D8.0mm_W2.5mm_P5.00mm
C2: 470u; CP_Radial_D10.0mm_P5.00mm_P7.50mm
C3, C4: 100n; C_Disc_D7.5mm_W2.5mm_P5.00mm
C5: 220u; CP_Radial_D8.0mm_P5.00mm
C6: 2.2u; C_Disc_D7.5mm_W2.5mm_P5.00mm
C11: 1u; C_Disc_D7.5mm_W2.5mm_P5.00mm
J1, J4: Conn_01x04_Pin; JST_XH_B4B-XH-A_1x04_P2.50mm_Vertical
J2, J3: Conn_01x03_Pin; JST_XH_B3B-XH-A_1x03_P2.50mm_Vertical
J5: Conn_01x06_Pin; JST_XH_B6B-XH-A_1x06_P2.50mm_Vertical
J6: Conn_01x02_Pin; PinHeader_1x02_P2.54mm_Vertical
J40: GPIO; PinSocket_2x20_P2.54mm_Vertical
JP1, JP2, JP3: Jumper_2_Small_Open; TestPoint_2Pads_Pitch2.54mm_Drill0.8mm
JPWR01: Molex_KK-396_A-41791-0002_1x02_P3.96mm_Vertical
JPWR02: JST_XH_B2B-XH-A_1x02_P2.50mm_Vertical
MH1, MH2: MountingHole_2.7mm_M2.5
Q1: IRF4905; TO-220-3_Vertical
Q2: 2N7000; TO-92_Inline
R1, R2, R5: 180; R_Axial_DIN0204_L3.6mm_D1.6mm_P7.62mm_Horizontal
R3, R4: 300; R_Axial_DIN0204_L3.6mm_D1.6mm_P7.62mm_Horizontal
R6, R9: 10k; R_Axial_DIN0207_L6.3mm_D2.5mm_P7.62mm_Horizontal
R7, R8: 1k; R_Axial_DIN0207_L6.3mm_D2.5mm_P7.62mm_Horizontal
R10: 10k; R_Axial_DIN0204_L3.6mm_D1.6mm_P7.62mm_Horizontal
R11: 22; R_Axial_DIN0207_L6.3mm_D2.5mm_P15.24mm_Horizontal
R12: 47; R_Axial_DIN0204_L3.6mm_D1.6mm_P7.62mm_Horizontal
U2: 74HC595; DIP-16_W7.62mm

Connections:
+3V3: J6.1, J40.1, J40.17
+5VD: C1.2, C2.1, C4.1, C5.1, J40.2, J40.4, JPWR02.1, Q1.2 (D), R1.1, U2.10 (~SRCLR), U2.16 (VCC)
/GPIO2/SDA1: J40.3, R9.1
/GPIO3/SCL1: J1.4, J40.5
/GPIO7/SPI0.CE1: J40.26, U2.12 (RCLK)
/GPIO10/SPI0.MOSI: J40.19, U2.14 (SER)
/GPIO11/SPI0.SCLK: J40.23, U2.11 (SRCLK)
/GPIO23: J40.16, JP3.1 (A), Q2.3 (D)
/GPIO26: J40.37, R8.1
GND: C1.1, C2.2, C3.2, C4.2, C5.2, C6.2, J1.1, J2.1, J3.1, J4.1, J5.1, J6.2, J40.6, J40.9, J40.14, J40.20, J40.25, J40.30, J40.34, J40.39, JPWR01.2, JPWR02.2, Q2.1 (S), R6.2, R12.1, U2.8 (GND), U2.13 (~OE)
unnamed: C6.1, R7.1, R9.2
unnamed: J1.2, R7.2
unnamed: J1.3, R8.2
unnamed: J2.2, JP2.2 (B)
unnamed: C11.2, J2.3, JP2.1 (A)
unnamed: J3.2, JP1.2 (B)
unnamed: J3.3, JP1.1 (A), R11.2
unnamed: C11.1, J4.2, R10.2
unnamed: J4.3, JP3.2 (B)
unnamed: J4.4, R11.1, R12.2
unnamed: J5.2, R5.2
unnamed: J5.3, R4.2
unnamed: J5.4, R3.2
unnamed: J5.5, R2.2
unnamed: J5.6, R1.2
unnamed: JPWR01.1, Q1.3 (S)
unnamed: Q1.1 (G), R6.1
unnamed: C3.1, Q2.2 (G), R10.1
unnamed: R5.1, U2.2 (QC)
unnamed: R4.1, U2.3 (QD)
unnamed: R3.1, U2.4 (QE)
unnamed: R2.1, U2.5 (QF)

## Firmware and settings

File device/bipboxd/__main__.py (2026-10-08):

"""Run the daemon skeleton.

    python3 -m bipboxd --fake-hardware         # anywhere
    sudo python3 -m bipboxd                    # on the Pi

Phase 1 wires up the lamps and the buttons only: there is no server connection
yet, so `--demo` is provided to walk the lamp states so the panel can be seen
working end to end.
"""

from __future__ import annotations

import argparse
import asyncio
import contextlib
import logging
import sys
from pathlib import Path

from .buttons import ButtonWatcher
from .calibration import Calibration, CalibrationError
from .hardware import open_hardware
from .leds import Lamp, LedController, Service

log = logging.getLogger("bipboxd")

DEMO_SEQUENCE = [
    (Service.DOWN, 3),
    (Service.SEARCHING, 4),
    (Service.CONNECTING, 4),
    (Service.CONNECTED, 4),
    (Service.AP_MODE, 5),
]


async def demo(leds: LedController, stop: asyncio.Event) -> None:
    """Walk every lamp through every state, so the panel can be eyeballed."""
    while not stop.is_set():
        for state, seconds in DEMO_SEQUENCE:
            if stop.is_set():
                return
            log.info("state → %s", state.value)
            for lamp in Lamp:
                leds.set_state(lamp, state)
            await asyncio.sleep(seconds)

        log.info("activity flashes")
        for lamp in (Lamp.TELEX, Lamp.VOIP):
            leds.set_state(lamp, Service.CONNECTED)
        for _ in range(6):
            leds.flash(Lamp.TELEX)
            await asyncio.sleep(0.3)

        log.info("telegraphy incoming")
        leds.set_forced_on(Lamp.TELEGRAPHY, True)
        await asyncio.sleep(1.5)
        leds.set_forced_on(Lamp.TELEGRAPHY, False)


def wire_buttons(buttons: ButtonWatcher, leds: LedController) -> None:
    """Local feedback only — the server half arrives in phase 3."""

    def telegraphy_pressed() -> None:
        log.info("telegraphy pressed")

    def telegraphy_released(held_ms: float) -> None:
        log.info("telegraphy released after %.0f ms", held_ms)

    def ptt_pressed() -> None:
        log.info("PTT pressed")
        leds.flash(Lamp.VOIP, hold_ms=400)

    def ptt_released(held_ms: float) -> None:
        log.info("PTT released after %.0f ms", held_ms)

    buttons.on_press("telegraphy", telegraphy_pressed)
    buttons.on_release("telegraphy", telegraphy_released)
    buttons.on_press("ptt", ptt_pressed)
    buttons.on_release("ptt", ptt_released)


async def main_async(args: argparse.Namespace) -> int:
    try:
        calibration = Calibration.load(Path(args.calibration) if args.calibration else None)
    except CalibrationError as e:
        log.error("calibration rejected: %s", e)
        return 2

    log.info("calibration: %s", calibration.led_bits)

    try:
        hardware = open_hardware(fake=args.fake_hardware)
    except Exception as e:
        log.error("no hardware: %s", e)
        log.error("run with --fake-hardware to work without a Pi")
        return 3

    leds = LedController(hardware, calibration)
    buttons = ButtonWatcher.from_calibration(hardware, calibration)
    wire_buttons(buttons, leds)

    stop = asyncio.Event()
    loop = asyncio.get_running_loop()
    with contextlib.suppress(NotImplementedError):
        import signal

        for sig in (signal.SIGINT, signal.SIGTERM):
            loop.add_signal_handler(sig, stop.set)

    tasks = [
        asyncio.create_task(leds.run(stop), name="leds"),
        asyncio.create_task(buttons.run(stop), name="buttons"),
    ]
    if args.demo:
        tasks.append(asyncio.create_task(demo(leds, stop), name="demo"))

    log.info("running (Ctrl-C to stop)")
    try:
        await stop.wait()
    finally:
        for task in tasks:
            task.cancel()
        await asyncio.gather(*tasks, return_exceptions=True)
        hardware.close()
    return 0


def main(argv: list[str] | None = None) -> int:
    parser = argparse.ArgumentParser(prog="bipboxd", description=__doc__.splitlines()[0])
    parser.add_argument("--fake-hardware", action="store_true", help="run without SPI or GPIO")
    parser.add_argument("--calibration", help="path to calibration.json")
    parser.add_argument("--demo", action="store_true", help="walk the lamp states")
    parser.add_argument("-v", "--verbose", action="store_true")
    args = parser.parse_args(argv)

    logging.basicConfig(
        level=logging.DEBUG if args.verbose else logging.INFO,
        format="%(asctime)s %(levelname)-7s %(message)s",
    )
    try:
        return asyncio.run(main_async(args))
    except KeyboardInterrupt:
        return 130


if __name__ == "__main__":
    sys.exit(main())

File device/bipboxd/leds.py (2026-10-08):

"""The four panel lamps: patterns, per-lamp state, and the driver loop.

One task owns the shift register (architecture.md §2.1), ticks at 25 ms, and
writes a byte only when it changes. Each lamp resolves to a pattern from its
service state, which an activity flash overrides while it lasts (Q31).
"""

from __future__ import annotations

import asyncio
import enum
import time

from .calibration import Calibration

# The controller tick. Every timing below is a multiple of it, so each phase
# runs at exactly its written duration — at 20 ms, 175 and 550 would quantise
# and no pattern would match its documentation (architecture.md §3.4).
TICK_MS = 25

# (on_ms, off_ms) phases, repeating.
PATTERNS: dict[str, list[tuple[int, int]]] = {
    "off": [(0, TICK_MS)],
    "on": [(TICK_MS, 0)],
    "slow": [(550, 550)],
    "fast": [(175, 175)],
    "heartbeat": [(200, 2800)],
    "ap": [(200, 200), (200, 200), (500, 200)],
}

# How long an activity flash lasts. It must be at least one full `fast` cycle,
# or the blink can be swallowed entirely: at 175/175 a 150 ms flash landing in
# the pattern's lit phase produces no visible change at all on a lamp that is
# already steady-on, which is exactly when activity matters most.
FLASH_HOLD_MS = 350


class Lamp(enum.StrEnum):
    TELEGRAPHY = "telegraphy"
    TELEX = "telex"
    VOIP = "voip"
    WIFI = "wifi"


class Service(enum.StrEnum):
    """What a subsystem is doing, independent of which lamp shows it."""

    DOWN = "down"
    SEARCHING = "searching"
    CONNECTING = "connecting"
    CONNECTED = "connected"
    AP_MODE = "ap_mode"


# Per-lamp state → pattern. Written out per lamp rather than shared, because
# the telegraphy lamp is deliberately inverted: its steady-on means "someone
# else is pressing" and "all well" is dark (architecture.md §3.4).
_STATE_PATTERNS: dict[Lamp, dict[Service, str]] = {
    Lamp.WIFI: {
        Service.DOWN: "off",
        Service.SEARCHING: "slow",
        Service.CONNECTING: "fast",
        Service.CONNECTED: "on",
        Service.AP_MODE: "ap",
    },
    Lamp.TELEX: {
        Service.DOWN: "off",
        Service.SEARCHING: "slow",
        Service.CONNECTING: "slow",
        Service.CONNECTED: "on",
        Service.AP_MODE: "off",
    },
    Lamp.VOIP: {
        Service.DOWN: "off",
        Service.SEARCHING: "slow",
        Service.CONNECTING: "slow",
        Service.CONNECTED: "on",
        Service.AP_MODE: "off",
    },
    Lamp.TELEGRAPHY: {
        Service.DOWN: "heartbeat",
        Service.SEARCHING: "slow",
        Service.CONNECTING: "slow",
        Service.CONNECTED: "off",
        Service.AP_MODE: "heartbeat",
    },
}


def pattern_for(lamp: Lamp, state: Service) -> str:
    return _STATE_PATTERNS[lamp][state]


def pattern_level(name: str, elapsed_ms: float) -> int:
    """Whether a pattern is lit at a given point in its cycle."""
    phases = PATTERNS[name]
    period = sum(on + off for on, off in phases)
    if period <= 0:
        return 0
    position = elapsed_ms % period
    for on, off in phases:
        if position < on:
            return 1
        position -= on
        if position < off:
            return 0
        position -= off
    return 0


class LedController:
    """Drives the lamps from their states. Not itself async-aware until run()."""

    def __init__(self, hardware, calibration: Calibration, clock=time.monotonic):
        self._hw = hardware
        self._cal = calibration
        self._clock = clock
        self._started = clock()
        self._states: dict[Lamp, Service] = dict.fromkeys(Lamp, Service.DOWN)
        self._flash_until: dict[Lamp, float] = {}
        self._flash_start: dict[Lamp, float] = {}
        self._forced_on: set[Lamp] = set()
        self._last_byte: int | None = None

    # ── State in ─────────────────────────────────────────────────────────────

    def set_state(self, lamp: Lamp, state: Service) -> None:
        self._states[lamp] = state

    def state(self, lamp: Lamp) -> Service:
        return self._states[lamp]

    def flash(self, lamp: Lamp, hold_ms: int = FLASH_HOLD_MS) -> None:
        """Signal activity: overrides the state pattern while it lasts.

        The flash carries its own phase origin so it always *starts dark*. On a
        lamp that is already steady-on — telex connected and then receiving —
        a gap is the only thing the eye can register; starting lit would show
        nothing. Repeated calls extend the flash without restarting its phase,
        so sustained activity reads as a continuous fast blink.
        """
        now = self._clock()
        if self._flash_until.get(lamp, 0) <= now:
            self._flash_start[lamp] = now
        self._flash_until[lamp] = now + hold_ms / 1000

    def set_forced_on(self, lamp: Lamp, on: bool) -> None:
        """Hold a lamp steady regardless of state.

        This is how the telegraphy lamp shows someone else holding their
        button: it is an event, not a state, and it outranks both.
        """
        if on:
            self._forced_on.add(lamp)
        else:
            self._forced_on.discard(lamp)

    # ── Rendering ────────────────────────────────────────────────────────────

    def byte_at(self, now: float | None = None) -> int:
        now = self._clock() if now is None else now
        elapsed_ms = (now - self._started) * 1000
        byte = 0
        for lamp in Lamp:
            bit = self._cal.bit(lamp.value)
            if lamp in self._forced_on:
                lit = 1
            elif self._flash_until.get(lamp, 0) > now:
                # Offset by the lit phase so the flash opens with a gap.
                since = (now - self._flash_start.get(lamp, now)) * 1000
                lit = pattern_level("fast", since + PATTERNS["fast"][0][0])
            else:
                lit = pattern_level(pattern_for(lamp, self._states[lamp]), elapsed_ms)
            byte |= lit << bit
        return byte

    def tick(self, now: float | None = None) -> int:
        """Render and write. Writing is skipped when nothing changed.

        The de-duplication lives here rather than in the hardware so that the
        fake and the real implementation behave identically — an interface
        whose two sides differ is not worth having.
        """
        byte = self.byte_at(now)
        if byte != self._last_byte:
            self._last_byte = byte
            self._hw.write_leds(byte)
        return byte

    async def run(self, stop: asyncio.Event | None = None) -> None:
        interval = TICK_MS / 1000
        try:
            while stop is None or not stop.is_set():
                self.tick()
                await asyncio.sleep(interval)
        finally:
            self._last_byte = 0
            self._hw.write_leds(0)

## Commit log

2026-10-03 chore: bootstrap the bipbox repository
    Design documents, development workflow, CI, and the standalone HAT
    wiring-test tool that unblocks hardware bring-up before any product
    code exists.
    CAD/ is deliberately left untracked for Guillaume to commit separately.
    telex/ is ignored: it is a separate repository kept locally for
    reference and ported by hand, not vendored.
2026-10-03 docs: add licensing — MIT for code, CERN-OHL-S v2 for hardware
    CERN-OHL-S is scoped to CAD/ so improvements to the board and enclosure
    stay open, while the software stays permissive like telex. The CERN text
    is the official copy from ohwr.org, unmodified.
2026-10-03 chore: automate releases with release-please
    Conventional Commits now drive versioning: the workflow maintains a release
    PR that bumps version.txt and CHANGELOG.md, and merging it tags and publishes
    the release.
    Configured with bump-minor-pre-major, so a breaking change before 1.0 bumps
    the minor rather than jumping to 2.0.
    version.txt is the single source of truth for the whole repo, since the server
    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
    [MB.step, bipbox-BoM.csv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]
2026-10-03 fix: pin the first release-please version to 0.1.0
    The first Release run proposed 1.0.0, which is release-please's default for an
    initial release but claims a stability this project has not earned.
    Also documents the repository setting release-please needs to open its PR,
    which is disabled by default and caused the first run to fail.
2026-10-07 feat(voip): add the phase 0b Janus AudioBridge spike harness (#4)
    ## What
    The phase 0b spike harness: a pinned Janus build, an AudioBridge room at
    8 kHz/PCMU and another at 16 kHz/Opus, a stdlib-only script to join as a
    plain-RTP participant, a CPU sampler, and a measurement procedure.
    ## Why
    This measures the two numbers that gate the entire media design
    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
2026-10-07 fix(device): repair the bit-walk, button monitor and mic gain (#7)
    Three bugs found during HAT bring-up, the capture gain the tool had no
    control over, and two hardware findings recorded in the architecture.
    ## Why — and what turned out NOT to be software
    Resolved by exporting a netlist from `CAD/KiCAD/bipbox.kicad_sch`, which
    settled two of the three reports as hardware facts:
    **1. `telex` was never learned (software bug).** The matcher accepted
    `answer.startswith(name[:4])`, and `"telex"` collides with
    `"telegraphy"` on four characters — so typing "telex" matched
    telegraphy, filed telex's bit under telegraphy, and left telex
    permanently unmapped, with no error shown. Fixed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
    [test_wiring_tool.py, wiring_test.py]
2026-10-08 docs: record the hardware lessons from box B's bring-up (#9)
    Three hardware findings from this week's bring-up, written down so they
    aren't rediscovered.
    **§3.1a — the 40-pin header has no keying, and it cost a Pi Zero W.**
    Fitted one row across, the HAT puts 5 V onto the Pi's 3V3 rail and onto
    GPIO2. The symptom was a board that blinked its ACT LED, never joined
    WiFi (the BCM43438 was already gone), and grew too hot to touch over two
    minutes. Documents the pin-by-pin consequence, a **shrouded 2×20
    header** as the fix for the next PCB revision, and an assembly procedure
    until then — including using the dead Pi as an alignment dummy, and the
    "pins 1/17 must read 0 V wi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
2026-10-08 feat(image): add the golden-image capture and restore workflow (#10)
    `image/prepare-for-capture.sh`, `image/capture.sh` and `image/README.md`
    — capture a prepared card into a small, re-flashable image, and write it
    back verified.
    Interim until pi-gen (phase 6). A cloned card is neither reproducible
    nor diffable, but it works today and Guillaume has boxes to build.
    ## Why these details matter
    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
2026-10-08 feat(device): add the bipboxd skeleton with fake-hardware support (#8)
    Phase 1's device half: calibration loading, a hardware interface with
    real and fake implementations, the LED state machine, and debounced
    button input. 82 tests (up from 32).
    ```
    device/bipboxd/
    ├── calibration.py # box A's JSON, validated
    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
